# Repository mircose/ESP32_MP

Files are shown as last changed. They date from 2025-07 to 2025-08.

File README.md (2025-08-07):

# ESP32_MP
## CD Quality Digital Audio Player and Streamer

You can watch a video explanation of this project [HERE](https://pages.github.com/)

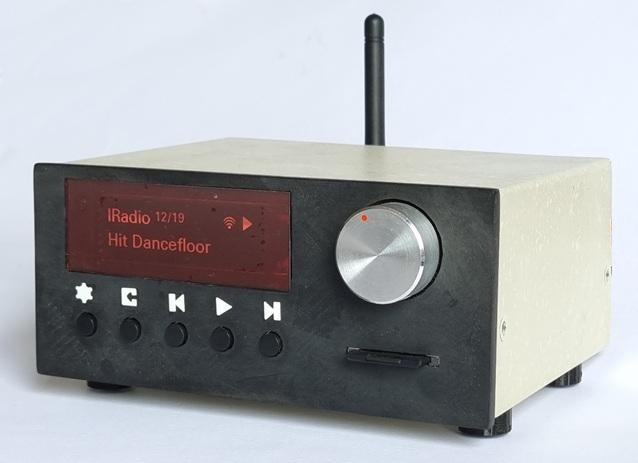
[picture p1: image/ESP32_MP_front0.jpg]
ESP32-MP_front


### This repository contains a complete project of Audio Player that implements:

*  Play from SD Card
*  Streaming from Internet Radio
*  Streaming from UPnP media server
*  Streamin from Bluetooth

### The main features are:

*  OLED Display for real time information
*  Button and knob to full control
*  Operated remotely with a IR remote control
*  Advanced Web Server for radio station manage

Supported audio formats: 	MP3, FLAC, WAV, AAC (up to 48 kHz, 16 bit)  
Maximum bit rate: 	1440 kbit/s (FLAC, WAV) 320 kbit/s (MP3, AAC)

### User Manuals:
See the manuals section for complete information
* User Manual Hardware to understand how to build it
* User Manual Software with operating instructions
* User Manual Firmware to understand how to test the hardware and load the firmware
* RMAA ESP32_MP Measure (pre out) with [RMAA Audio Test Software](https://audio.rightmark.org/products/rmaa.shtml)

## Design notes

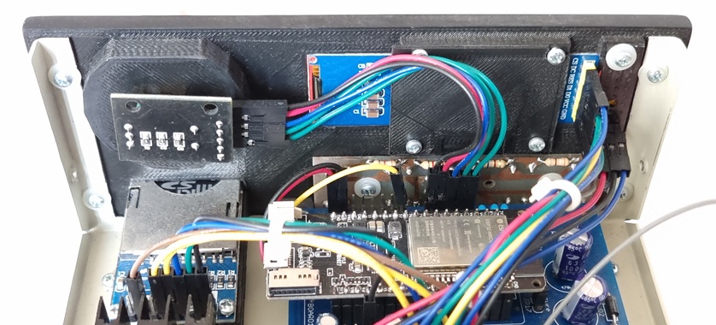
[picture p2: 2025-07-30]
image/ESP32_MP_internal2.jpg

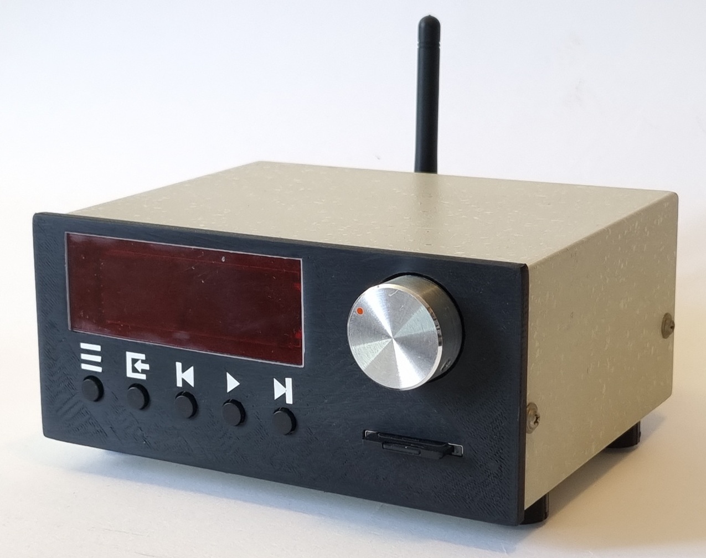
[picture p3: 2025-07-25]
image/ESP32_MP_front2.jpg

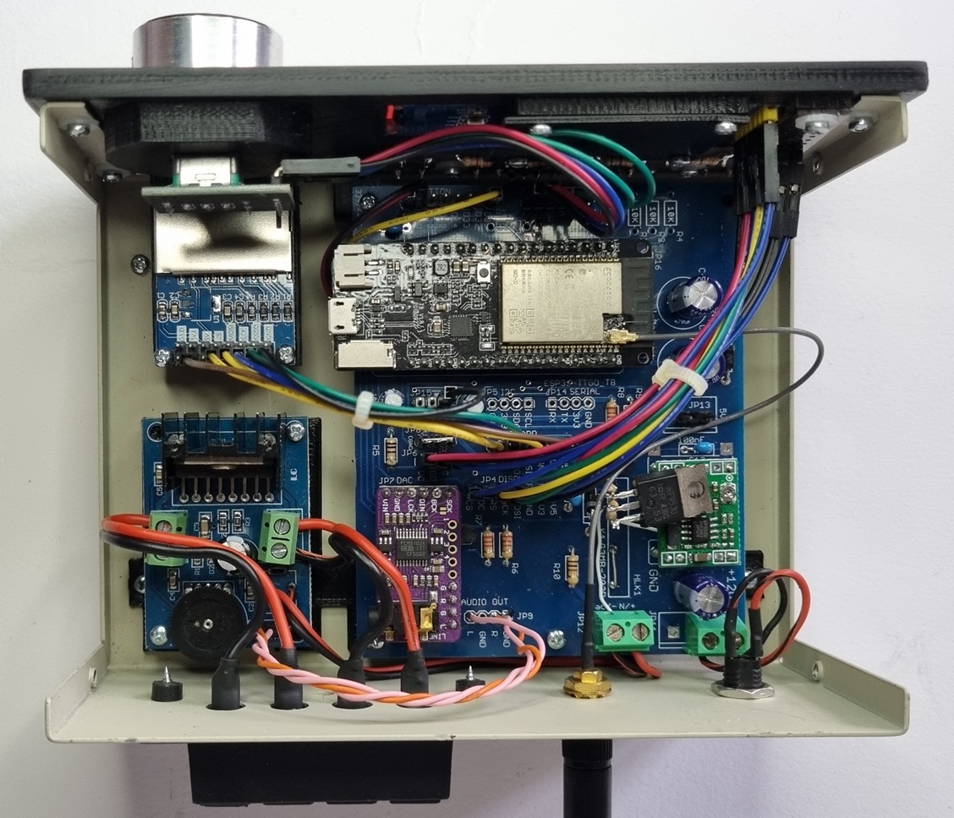
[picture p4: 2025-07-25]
image/ESP32_MP_internal.jpg

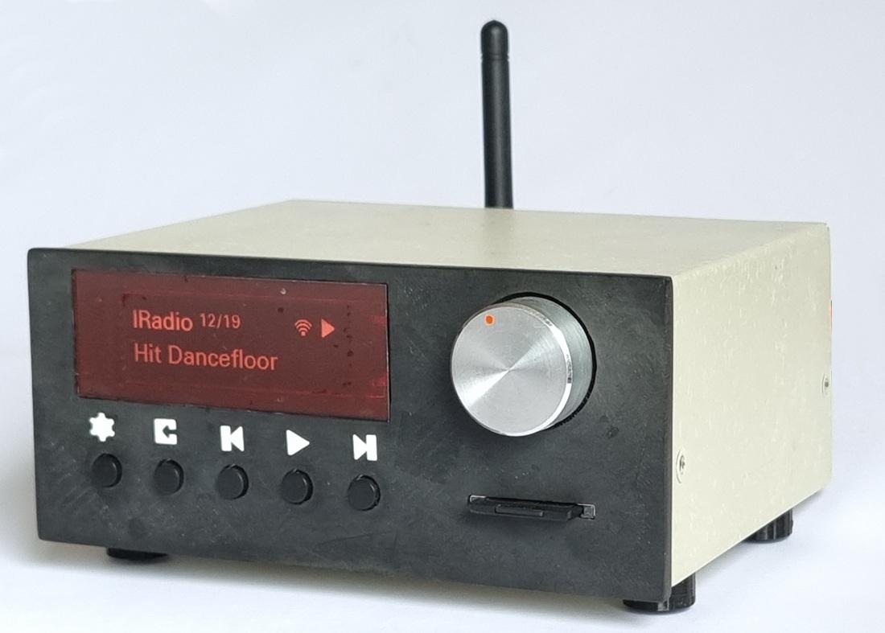
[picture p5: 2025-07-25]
image/ESP32-MP_front.jpg

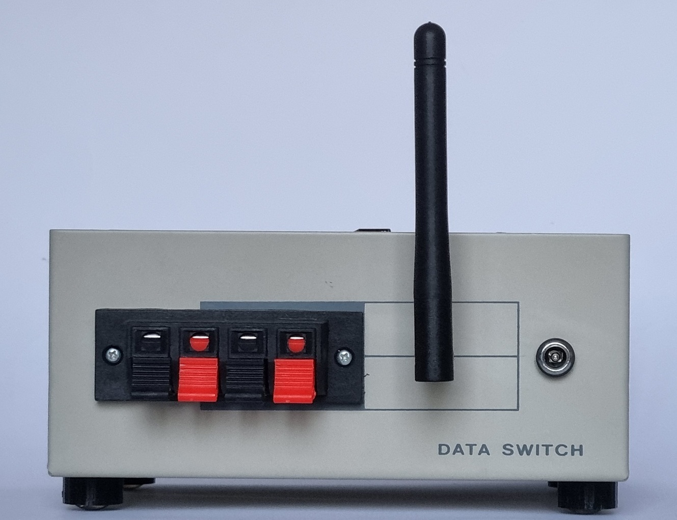
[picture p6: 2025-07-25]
image/ESP32_MP_rear.jpg

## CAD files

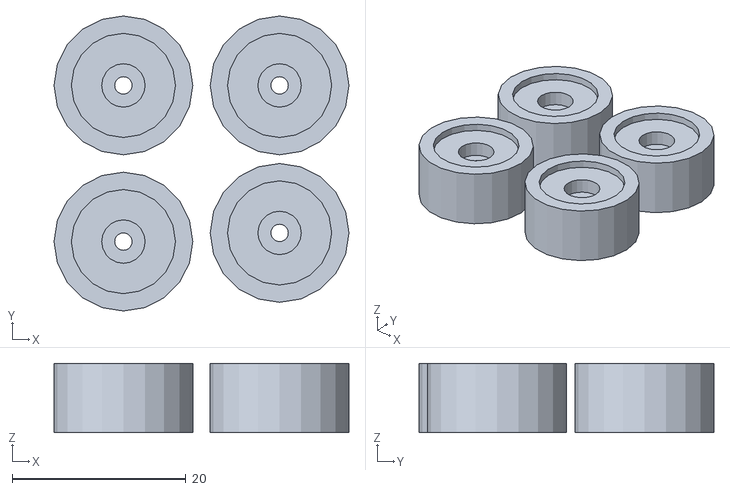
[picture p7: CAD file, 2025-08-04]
3D files/ESP32_MP_feet.stl
34.0 x 34.0 x 8.00

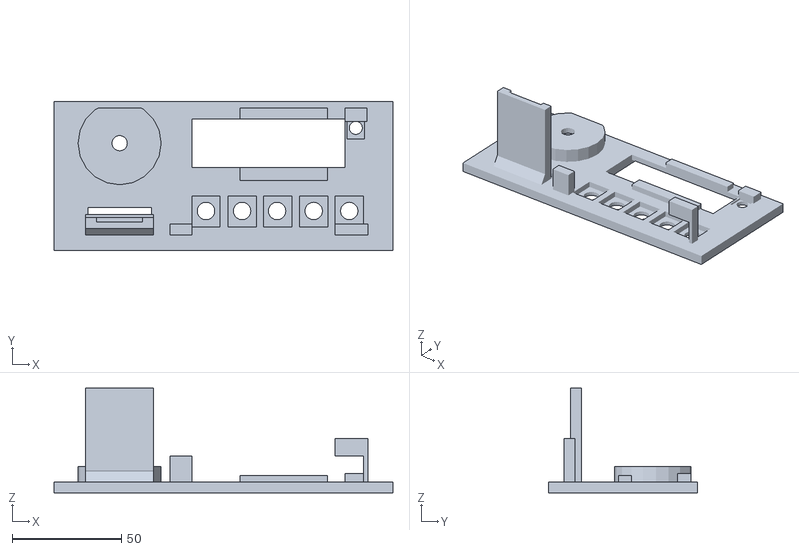
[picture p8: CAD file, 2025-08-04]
3D files/ESP32_MP_front.stl
155.0 x 68.0 x 48.0

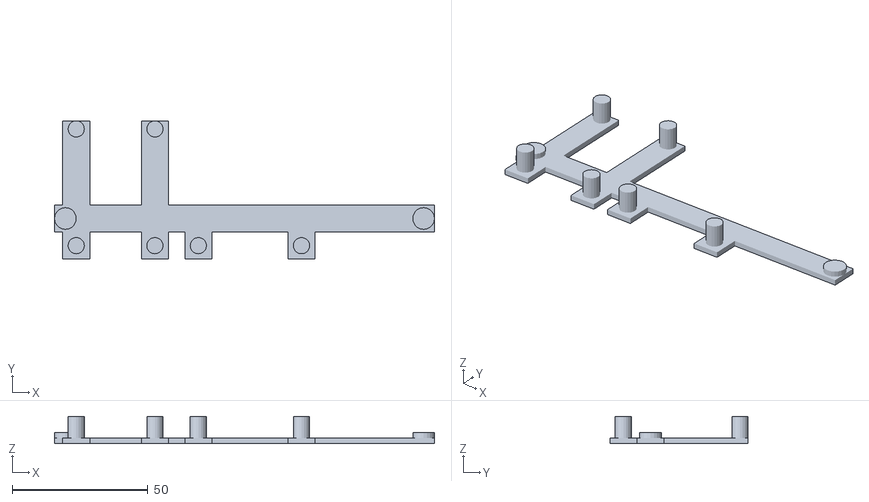
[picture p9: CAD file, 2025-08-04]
3D files/ESP32_MP_support.stl
140.0 x 51.0 x 10.0

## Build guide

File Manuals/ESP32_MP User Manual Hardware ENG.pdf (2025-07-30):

# ESP32_MP

# Digital Music Player and Streamer

## User Manual Hardware

Version ENG july 2025

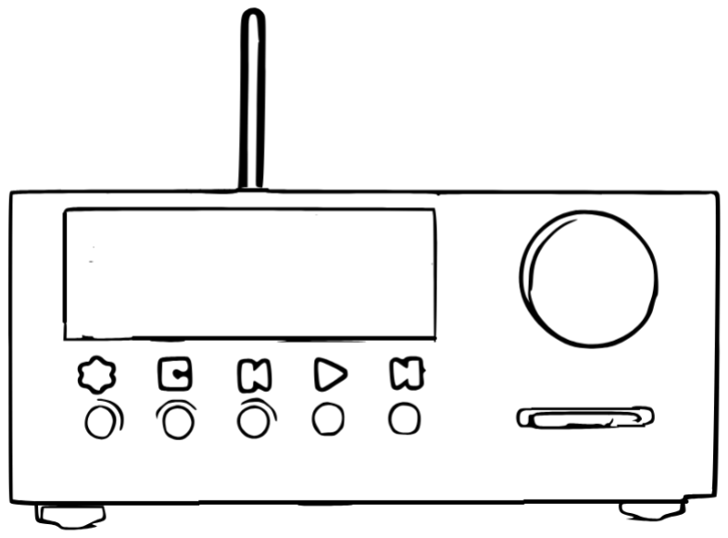
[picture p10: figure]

CD Quality Digital Music Player and Streamer Streaming from Internet Radio
Streaming from UPnP media server
Streamin from Bluetooth
Play from SD Card

# Table of contents

1. Introduction and disclaimer
2. Main board
3. Push button board
4. Componets modify
5. Assembly option#1
6. Assembly option#2
7. Assembly in case

# 1.Introduction and disclaimer

This document describe construction and assembly the ESP32_MP multimedia player. This is a hobbyist, non-commercial project; therefore, no support is provided, nor is it guaranteed to work properly. It is recommended that you attempt this project only if you have some familiarity with electronics. The author assumes no responsibility for any damage or injury resulting from the realization of this project. This proposal is only one possible solution; everyone can make any changes and improvements they deem appropriate.

# 2.Main board

All the project files are available in the GitHub repository. Below is the wiring diagram of the main electronic board. The public version uses the ESP32_MP_PCB_V2_REV2 files; in my project, I used the ESP32_MP_PCB_V2 files.

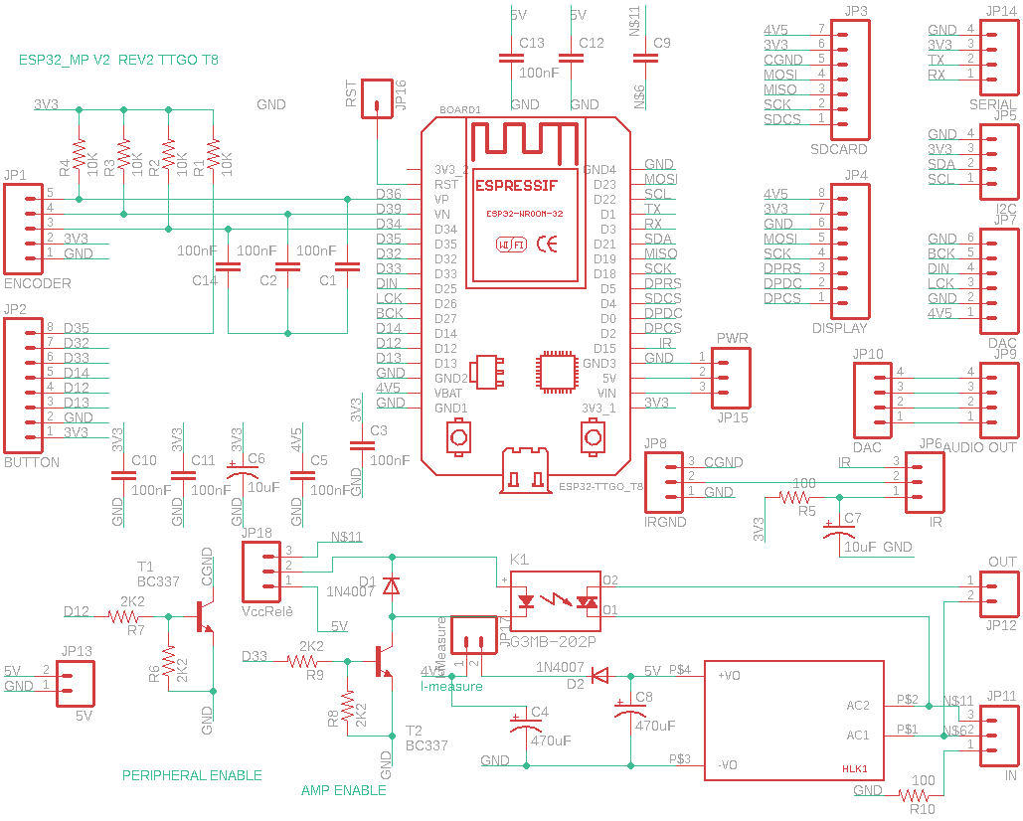
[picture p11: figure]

ESP32_MP Main Board schematic

ESP32_MP Main Board component layout

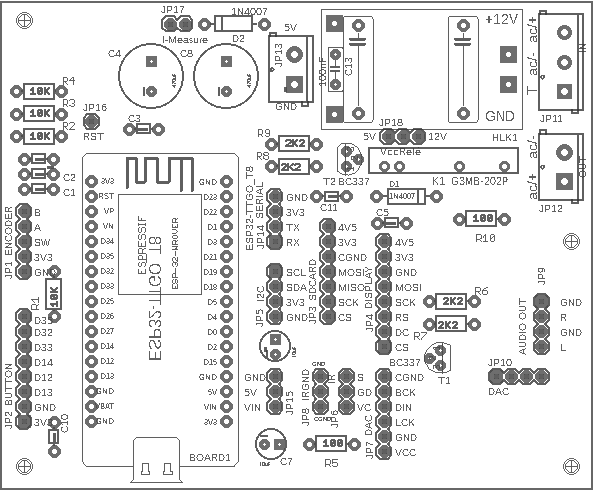
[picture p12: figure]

List of components:
name | Value | note
R1, R2, R3, R4 | Not used | already present on encoder breakout
R5, R10 | Resistor 100 1/4W
R6, R7, R8, R9 | Resistor 2k2 1/4W
D1, D2 | Diode 1N4007
T2 | BJT BC337
T1 | Not used
C1, C2, C3, C5, C9, C10, C11, C12, C13 | Capacitor 100nF 63V
C4, C8 | Capacitor 470uF 25V
C6, C7 | Capacitor 10uF 25V
JP7, JP9, JP10, MCU | Strip Female 2,54mm
JP1, JP2, JP3, JP4, JP6, JP8, JP12, JP15, JP17, JP18 | Strip Male 2,54mm
JP5, JP13, JP14, JP16 | Not used | Expansion connector
JP11, JP12 | Connector screw 5mm
K1 | See next

Additional components and break out board:

name | Value | SKU Futuranet.it

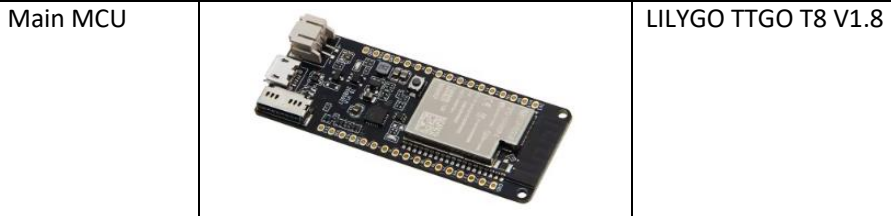
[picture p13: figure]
Main MCU; LILYGO TTGO T8 V1.8

DAC | PCM5102A | 2846-I2SPCM5102A
Encoder W/button | Encoder breakout 12mm YC093 | 8300-YC093
IR Sensor | IR38DM | 8220-IR38DM
Display | OLED SPI 2,08” 256x64 HM25664A208W02 | 2846-SPIOLED208

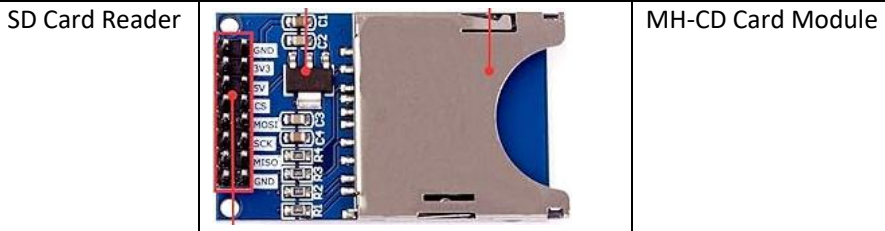
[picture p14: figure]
SD Card Reader; MH-CD Card Module

IR remote control | H96MAX model

# 3.Componets modify

For optimise system consumption and functionality It is recommended (but not necessary) some modify to components.
1. Remove LDO from SD Card Module.

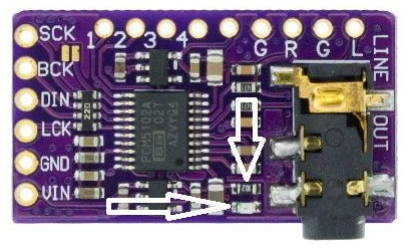
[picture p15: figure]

2. Cut wire of LED or remove LED or Remove resitor from DAC Module.

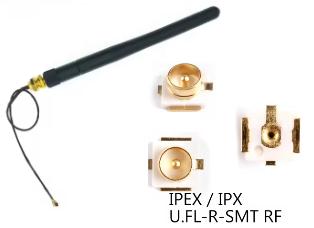
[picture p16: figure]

3. Most ESP32 boards come with an internal antenna. If you use a metal case, this may affect the WiFi signal. In this case, you'll need to add an external antenna to the ESP32 module using the appropriate antenna pads. You need to get an antenna with the corresponding IPX connector compatible with ESP32 board. Very carefully solder the ipx connector on the esp32 board and move the resistor that switches from internal to external antenna.

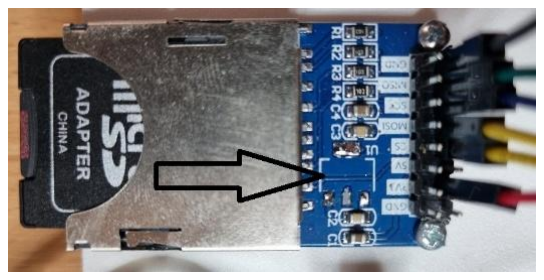
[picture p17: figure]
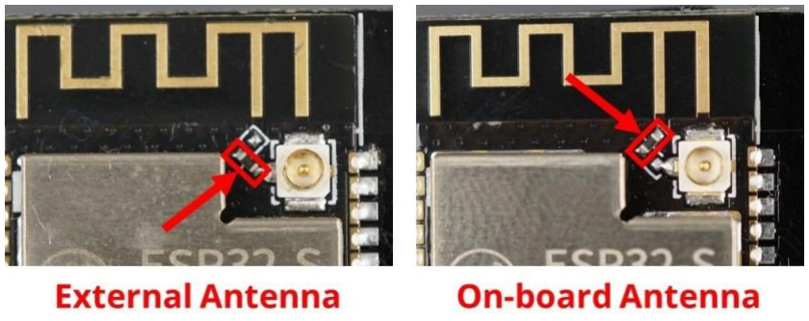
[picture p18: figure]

# 4.Push button board

ESP32_MP Push button board schematics

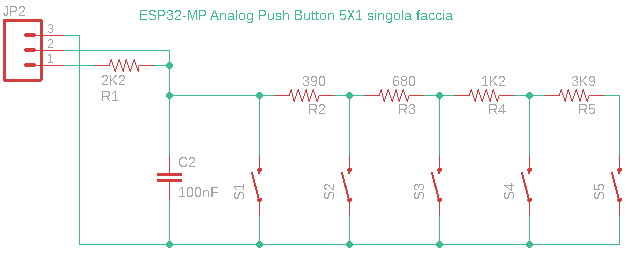
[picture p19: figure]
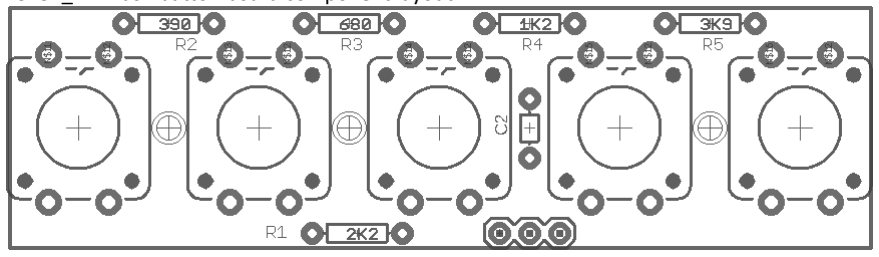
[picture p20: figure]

ESP32_MP Push button board component layout

List of components:
name | Value | note
R1 | Resistor 2k2 1/4W
R2 | Resistor 390 1/4W
R4 | Resistor 1k2 1/4W
R5 | Resistor 3k9 1/4W
C2 | Capacitor 100nF
JP2 | Strip Male 2,54mm
P1, P2, P3, P4, P5 | Push button 12x12mm

# 5.Assembly options #1

There are two possible configurations based on the type of power supply and amplifier. In option #1 use a 12VDC power supply by AC/DC Wall power adapter for powered the player. The amplifier is powered by 12VDC ( the power of amplifier is limited by this voltage).

List of components:
name | Value | SKU Futuranet.it
Power adapter | 230VAC/12V 1A | 8260-PSSE1210
HLK1 DC/DC Converter | 12VDC to 5VDC step down converter | 3085-MP1584ADJ
Power plug | Panel plug 5,5 x 2,1 mm | 1606-DCPLUG

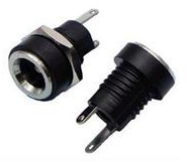
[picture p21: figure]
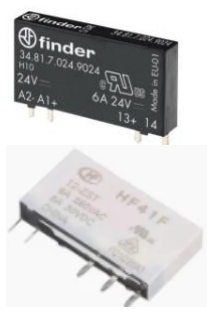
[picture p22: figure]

K1 | Finder 34.51 12V OR Finder 34.81.7.012.9024 OR HF41F 12-ZS OR HF41F 12-HS OR DIY MOSFET RELAY | For power amplifier
Power amplifier | TDA7297 Amplifier board Single power supply 12VDC 8+8W @12V | If you want only preamplifier output this isn’t necessary.

K1 DIY MOSFET RELAY

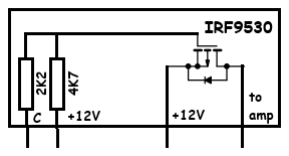
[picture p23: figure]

Alternatively the 230Vac/12VDC power supply can be inserted
inside the case:

Assembly schematics Please Note:

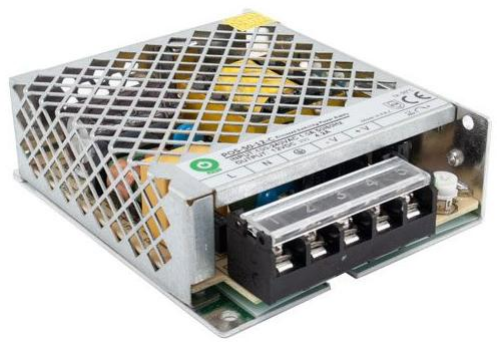
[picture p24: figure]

JP17 it's a useful connector to measure absorbent current. Short circuit the pins in normal operation. JP13 it’s used to measure ESP32 board power voltage.
JP8 it's possible to reduce current consumption in standby mode disable gnd power from SD card, DAC and IR sensor by T1. But not great advantage, in normal use short circuit the three pins.
JP6 for max stability connect 100nF capacitor as to close beetwin pin Vcc e GND of IR38DM IR sensor. JP5, JP14 and JP15 are connectors for future expansion functions.
JP18 connect the central pin to 12V, this is a voltage to control relay.
Connect the power adapter 230Vac/12VDC at main power plug.

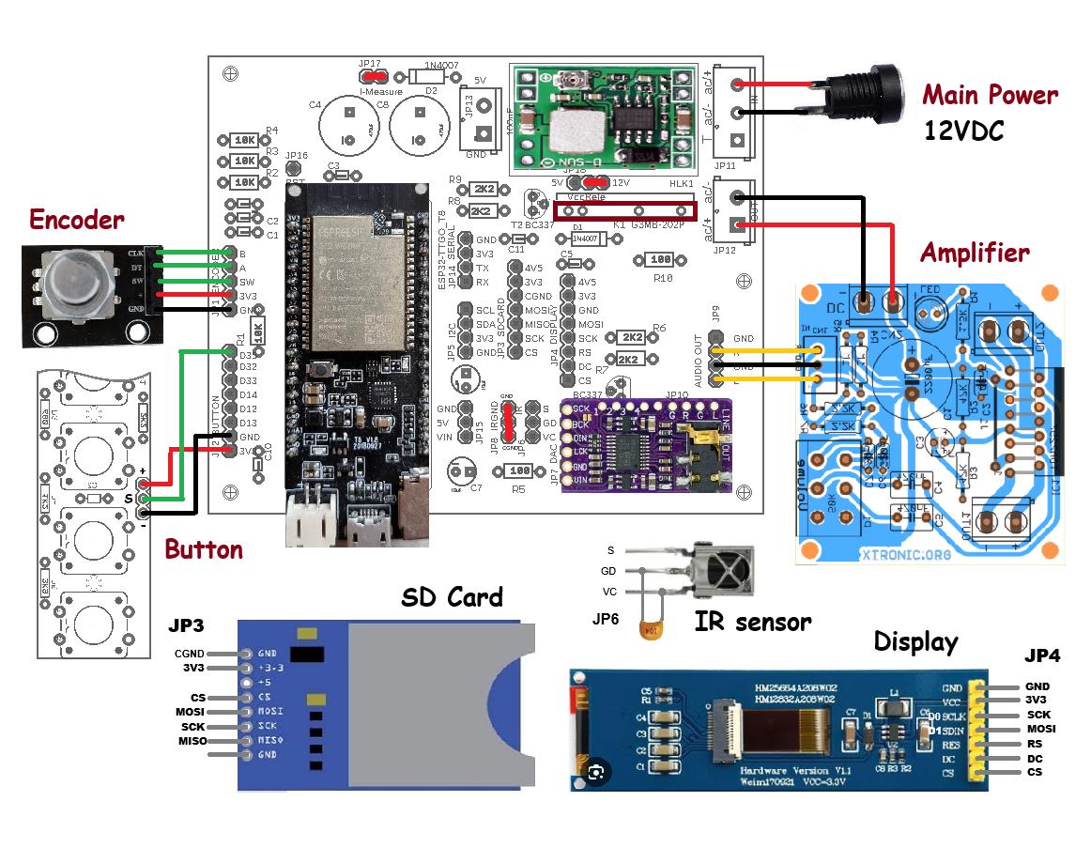
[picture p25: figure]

# 6.Assembly option #2

In option #2 use a 230Vac power supply and secondari AC/DC converter for powering amplifier. There is not limitation amplifier power.

List of components:
name | | Value | SKU Futuranet.it

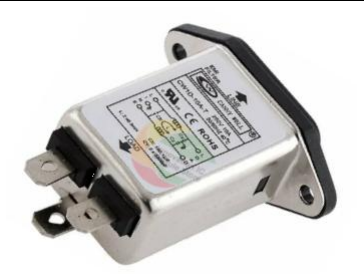
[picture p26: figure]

Power plug | OR | VDE panel plug 250 VAC | 8300-POWERSOCKET2

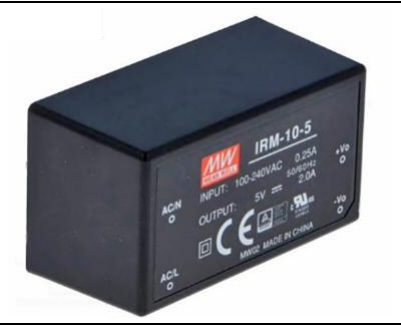
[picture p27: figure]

HLK1 AC/DC adapter | | 230Vac to 5VDC adapter | 8420-IRM-10-5
K1 | | State solid Realy Omron G3MB-202P Input 5VDC Output 240Vac 2A | 8300-YL051

For power amplifier (Example): Transformer 230Vac/24+24Vac Converter 2xAC/2xDC
Power amplifier
There are some options…

Assembly schematics Please Note:
JP17 it's a useful connector to measure absorbent current. Short circuit the pins in normal operation. JP13 it’s used to measure ESP32 board power voltage.
JP8 it's possible to reduce current consumption in standby mode disable gnd power from SD card, DAC and IR sensor by T1. But not great advantage, in normal use short circuit the three pins.
JP6 for max stability connect 100nF capacitor as to close beetwin pin Vcc e GND of IR38DM IR sensor. JP5, JP14 and JP15 are connectors for future expansion functions.
JP18 connect the central pin to 5V, this is a voltage to control relay.
Connect the power supply 230Vac at main power plug

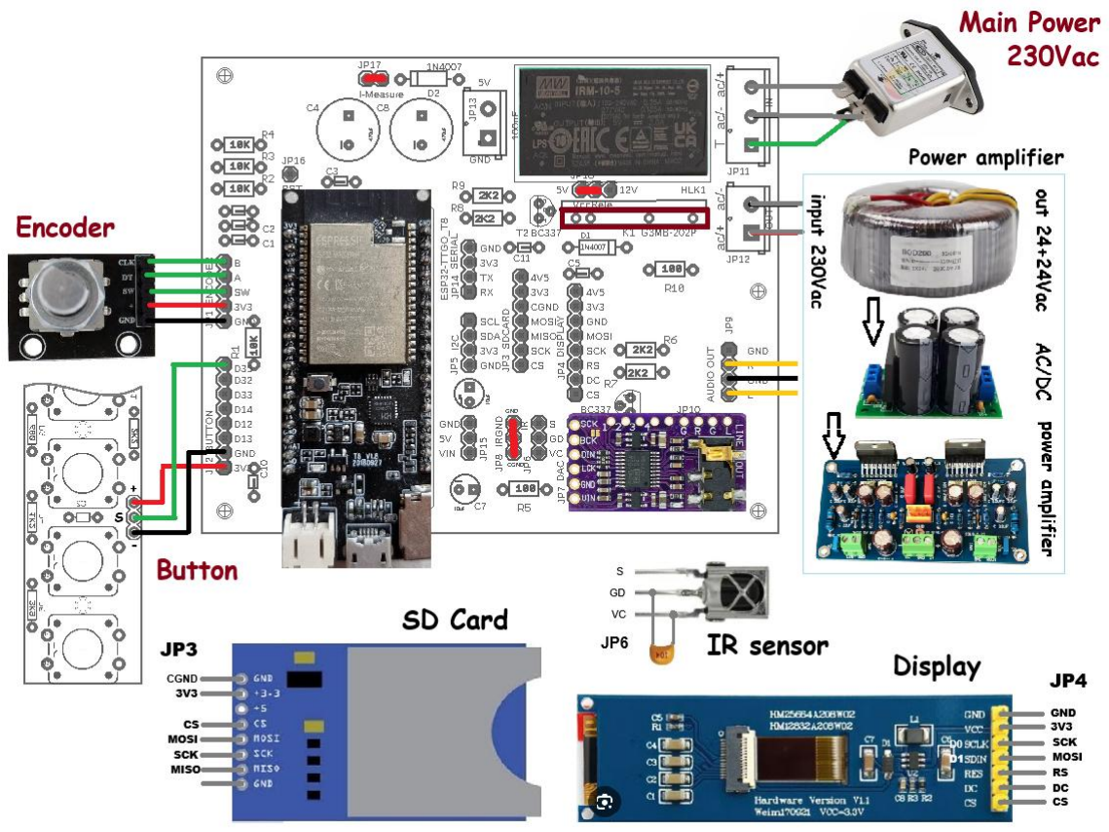
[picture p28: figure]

Additional options for the power amplifier:

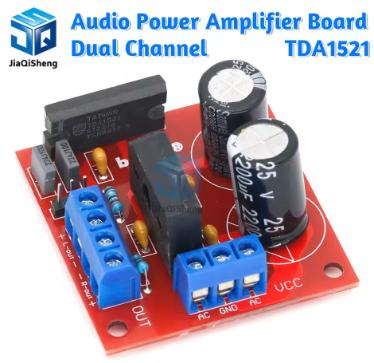
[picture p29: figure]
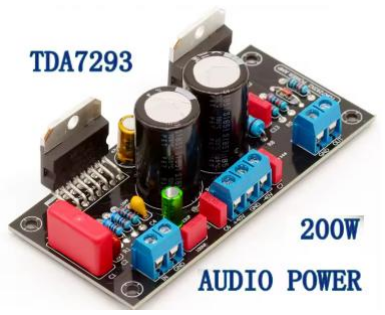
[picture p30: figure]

# 7.Assembly in case

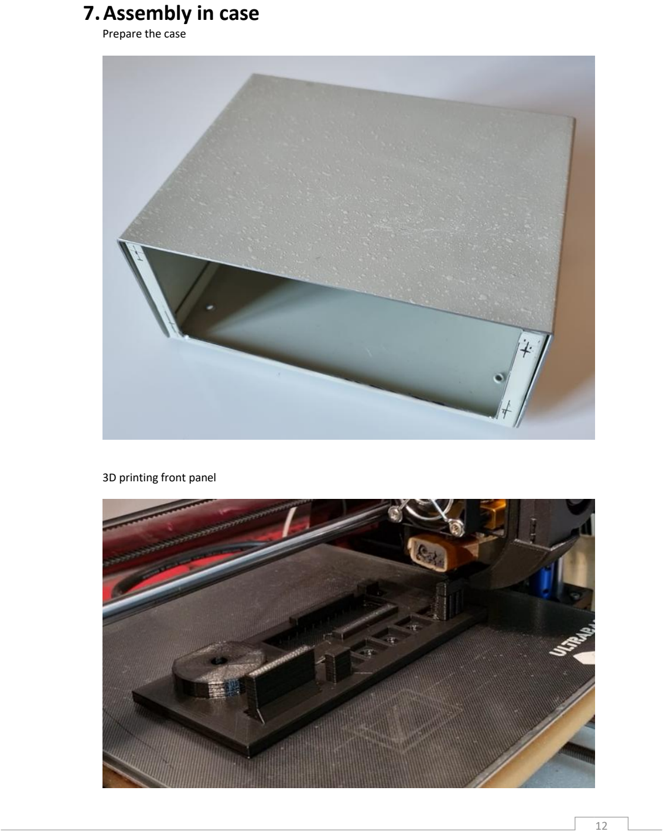
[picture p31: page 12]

Prepare the case

3D printing front panel

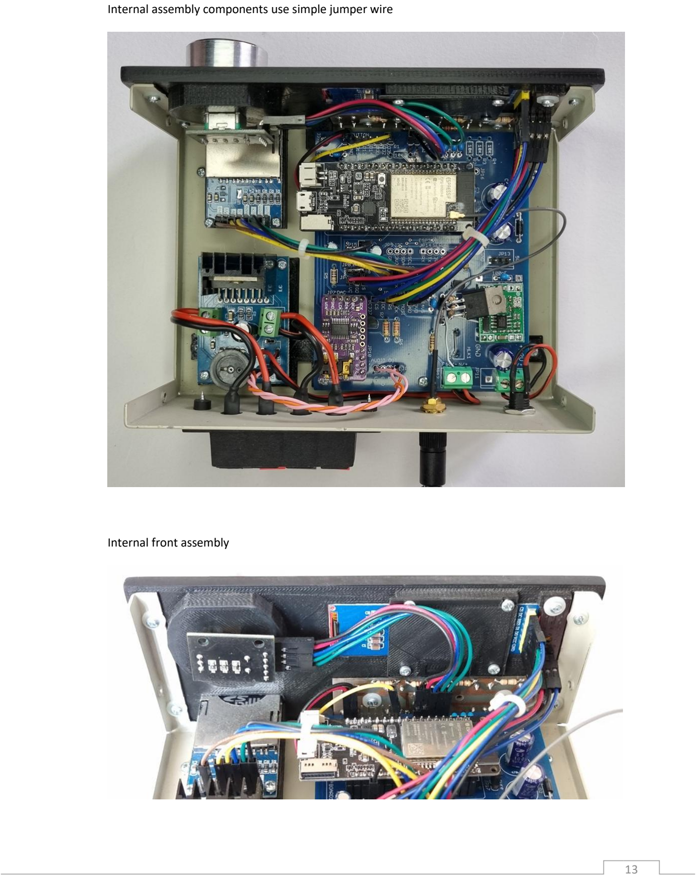
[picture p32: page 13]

Internal assembly components use simple jumper wire

Internal front assembly

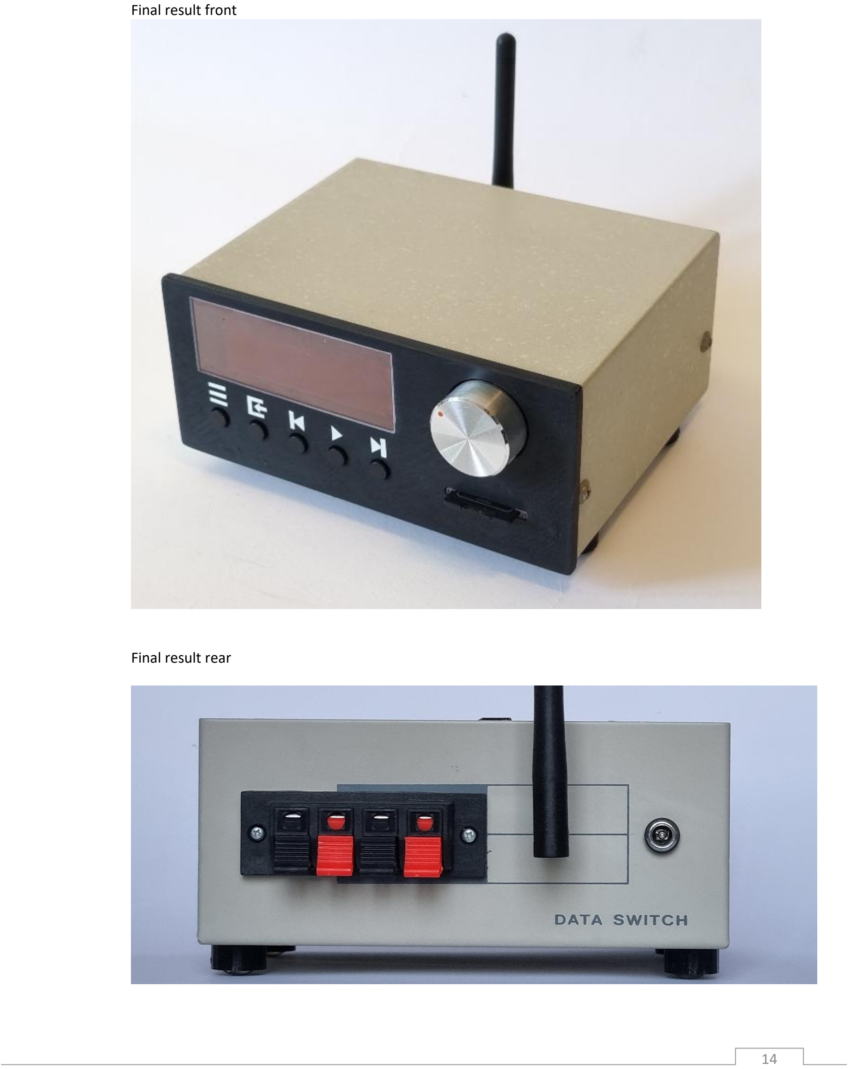
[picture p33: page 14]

Final result front

Final result rear

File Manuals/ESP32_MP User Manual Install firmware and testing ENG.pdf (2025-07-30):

# ESP32_MP

# Digital Music Player and Streamer

## Install Firmware and testing

Version ENG july 2025
firmware version 20250724


CD Quality Digital Music Player and Streamer Streaming from Internet Radio
Streaming from UPnP media server
Streamin from Bluetooth
Play from SD Card

# Content

1. Testing
2. Install firmware
3. First start

# 1.Testing

Once the hardware has been completed by assembling all the components as described in the relevant manual, it’s possible to install the firmware that enables all the player's features. in this case you can skip the following chapters and read the chapter relating to the firmware installation. If you want it’s possible testing each individual component. To perform the tests described below you need to have the necessary skills in using the Arduino IDE. Testing requires the Arduino IDE on PC, connected via serial to the ESP32 MCU board.

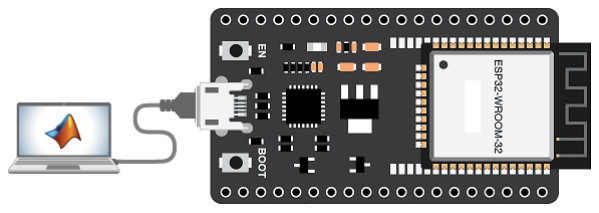
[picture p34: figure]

The online repository at https://github.com/mircose/ESP32_MP provides all the documentation needed to build and test the player. Among the files are some sketches that can be used to test a specific hardware component of the project. These sketches must be opened in the Arduino IDE and uploaded to the ESP32 module via the serial connection. for some sketches it will be necessary to install the appropriate library. All these sketches use the Arduino Serial Monitor to provide a performance report. The expected reports are available in each sketch's folder.

# 2.Install Firmware

Given the complexity of the project and the difficulty of managing many libraries, some of which have been modified, the precompiled .bin file is provided, which is much easier to install. Download the latest firmware version in .bin format from the repository.
Dowload Espressif Flash Download Tools from https://www.espressif.com/en/support/download/other-tools

Connect the player to the PC with the serial cable and run Flash Download tools. Set ESP32 Chip Type
WorkMode Develop
LoadMode UART

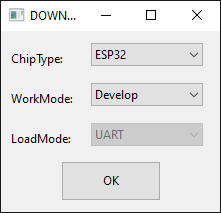
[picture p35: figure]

Open ESP32_MP_xxxxxxxx.bin compiled firmware and set with image below. Make sure to check the file selection and enter the value 0x0 as the address, then click START.

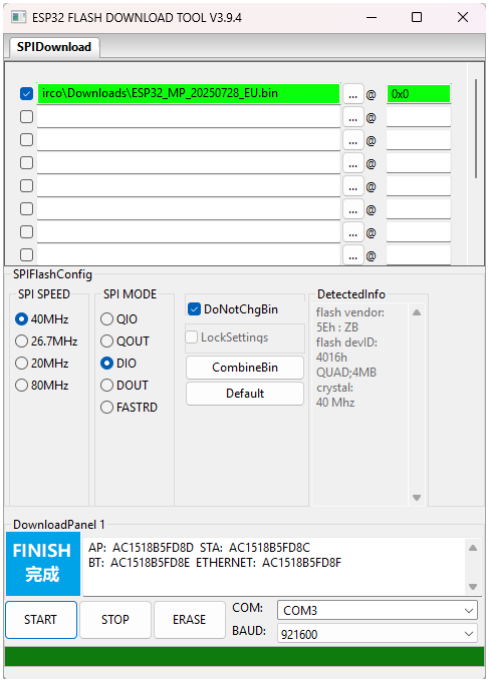
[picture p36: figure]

wait for the operation to complete.

# 3. First start

After completing the firmware upload, unplug the serial cable. If the player was powered, press the reset button on the ESP32 board to start running the program. If the player was not powered, power it on.
At first start-up, the default settings are present and the first prompt on the screen tells you to select the listening source.

If you select SD Player or Bluetooth Streamer don’t need to configure WiFi network.

If you select Internet Radio or UPnP you need to configure WiFi network.

For details on how to set up your WiFi network and player features please see the file ESP32_MP User Manual Software ENG.pdf

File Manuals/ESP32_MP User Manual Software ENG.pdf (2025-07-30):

# ESP32_MP

# Digital Music Player and Streamer

## User Manual Software

Version ENG july 2025
Firmware version 20250726


CD Quality Digital Music Player and Streamer Streaming from Internet Radio
Streaming from UPnP media server
Streamin from Bluetooth
Play from SD Card

# Content

1. Components and functions
2. Menu configuration
3. WiFi configuration
4. internet Radio
5. Radio Station configuration
6. UPnP Player
7. SD Player
8. Bluetooth
9. Remote control
10. Display
11. Characteristics

# 1.Components and function

The media player features a display for information, a series of buttons, and a multifunction knob that also functions as a button. Description of the features available on the front of the player.

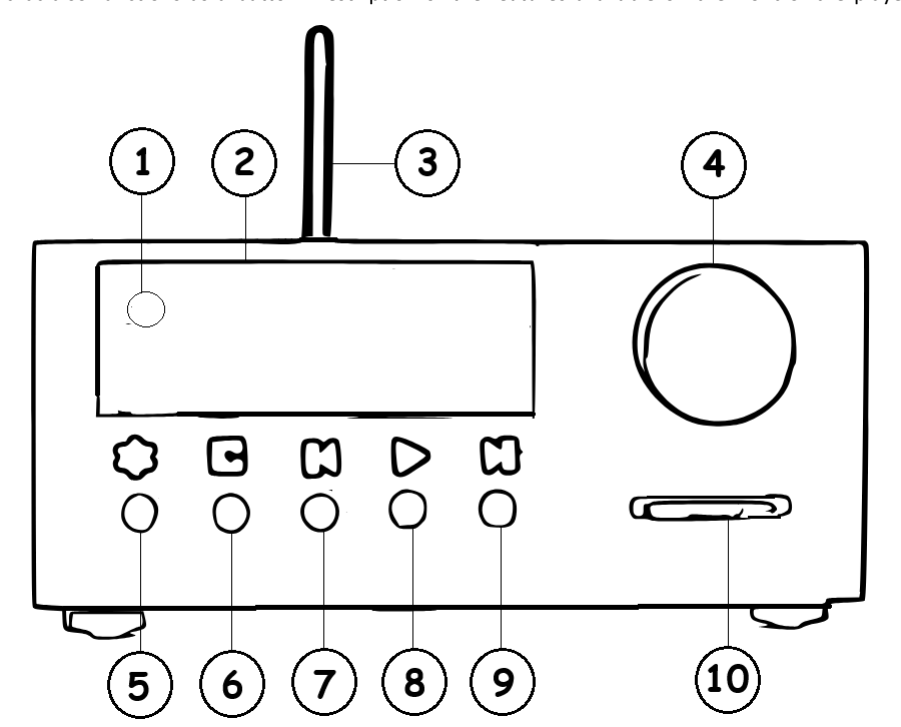
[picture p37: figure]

1 IR sensor
2 Display
3 Antenna
4 Knob set volume / select track (press to confirm) / On-Off 5 Settings
6 Input Select
7 Track forwards
8 Play / Pause
9 Track backwards
10 SD Card slot

To turn the device on, briefly press the knob; to turn it off, press and hold the knob. During standby mode, the unit can be programmed to display the date and time on the display. In standby mode, power consumption is higher, and Wi-Fi and internet access are required for automatic clock synchronization. If you choose not to display the clock in standby, power consumption will be lower, and internet access will only be required when listening to internet radio.

Description of the features available on the back of the player.

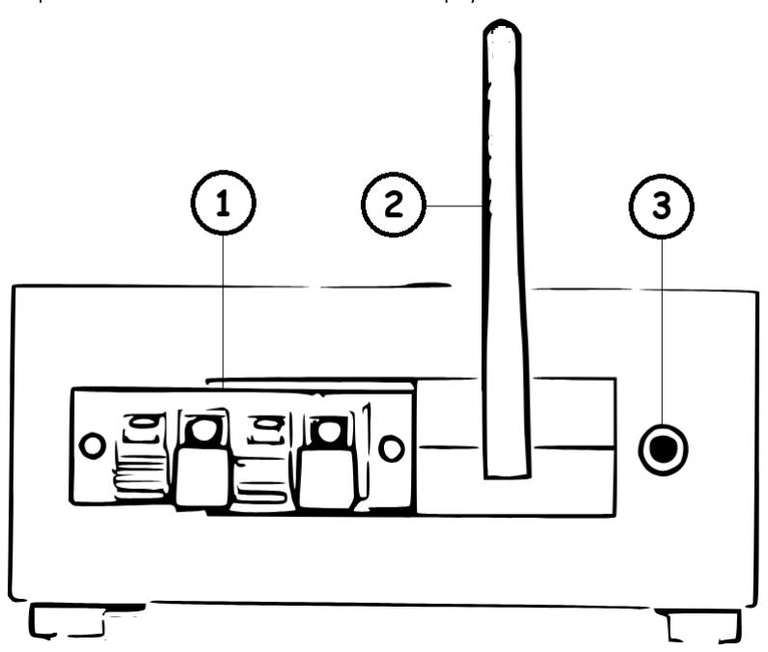
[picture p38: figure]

1 Speaker connector
2 Antenna
3 Power connector

Connect the speakers to the left and right speaker jacks (speaker output) on the back of the unit. To do this, press the spring clips and insert the loose wire ends into the designated openings.
Connect the external antenna for WiFi access. Connect the external power supply or power plug, depending on the hardware version you have assembled.

# 2.Menu configuration

Read Favor. radio
Your favorite radio stations are saved in the ESP32's internal memory, and they can be read and added to the playlist. The next command (Read radio in SD) lets you load the list of stations saved in SD into the playlist. If this was your last setting, you will find it every time you start the player.

Read radio in SD
Select the radio playlist on the SD card. In the SD card, you can create a folder called RadioPlaylist containing Text files. Each file contain the list of stations divided by genre or content. For example you can create (internal RadioPlaylist folder) a file called Country.txt that contains only country radio stations. The lines in this file is in format: “station name” followed by comma followed by “URL” example:

Radio Country,https://stream.laut.fm/country

Country NY,http://ns2.kmeathosting.com:8000/wtrb Music Country,http://s1.logical.systems:9000/
Country Music FM,https://stream.laut.fm/countrymusicfm

Read audio in SD
Loads the songs present in SD (mp3, FLAC...) into the play list (this is done automatically every time you select SD Player).

Scan UPnP Server
It scans the network for all media players and then allows you to select the one that will be the default each time you start the device.

No repeat
The selected song will repeat only once.

Repeat single
The selected song repeats continuously.

Repeat all
Plays all songs in sequence.

Repeat random
Play all songs in shuffle mode.

NB Repeat modes are only valid in SD Player and UPnP Player mode.

Configure WiFi
Set up your WiFi access credentials.

Disable Amp
Disable amplifier power.

Enable Amp
Enable amplifier power.

StandBy deep
Standby in deep sleep mode. Power ON only via knob button.

StandBy clock off
Standby without clock on display. Power ON via knob button and remote control.

StandBy clock on
Standby with clock on display. Power ON via knob button and remote control. Valid only for Central European country.

Info
Displays the firmware version and network name.
The firmware version corresponds to the date it was uploaded.

NB Some functions are only active when you are in the relevant mode. NB For Standby detail view technical specifications manual

# 3.WiFi configuration

The device can operate in SD Player and Bluetooth streamer modes without requiring WiFi access. To use the UPnP Player functionality, you must connect to a WiFi network with a discoverable UPnP server. For Internet Radio functionality, you must be connected to a WiFi network with Internet access.
Use the buttons on the main unit to access the menu, rotate the dial to Configure WiFi, and then confirm by pressing the dial.

The ESP32 module will configure a local network (access point) to which you should connect with a mobile device. Open settings in you mobile devoce and connected to the network named ESP32_MP, launch your browser and enter the URL 192.168.4.1. The Web Server for connection management will open. Click Configure WiFi and follow the instructions on the display.
Once the configuration is complete, the device will automatically reboot.

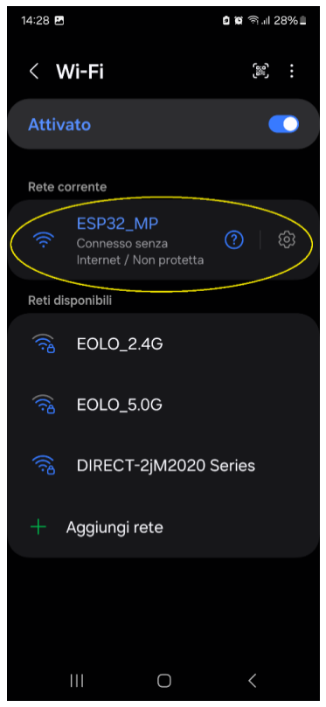
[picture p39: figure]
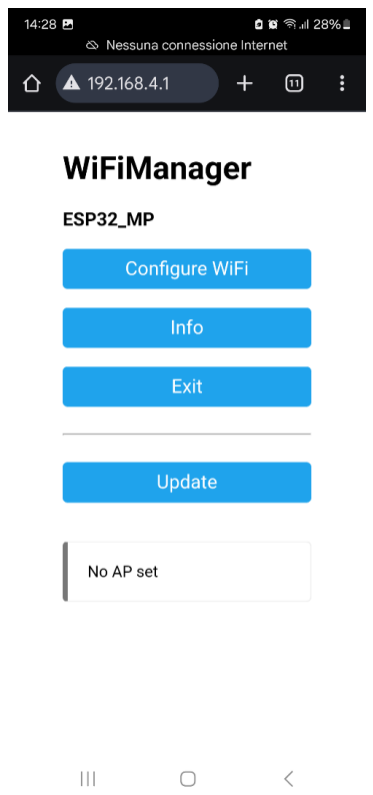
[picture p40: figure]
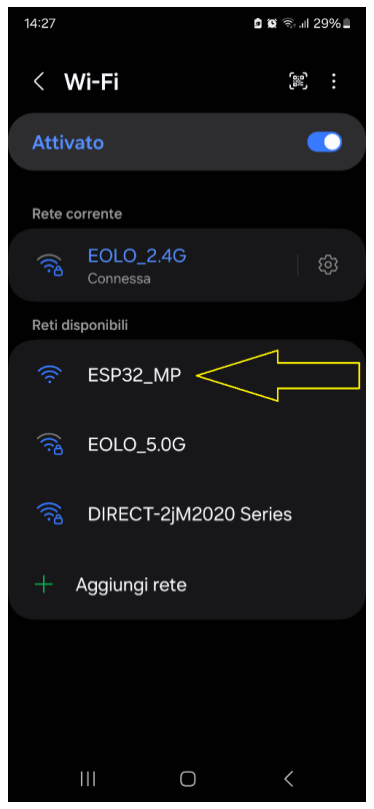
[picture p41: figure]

# 4.Internet Radio

Press the source selection button on the main unit or remote control until iRadio appears on the display. The software will automatically load the default songs saved in the internal memory into the playlist. Playback will automatically start from the last selected station. Use the Next and Previous buttons to select the next or previous song. By clicking the knob or OK on the remote control, you can open and scroll through the song list for easier selection..

# 5.Radio station configuration

In Internet Radio mode, open a browser and type http://ESP32_MP. This will open the Web Server for managing radio stations saved in the device's internal memory. From this screen, you can read the list of stored radio stations and control playback. You can use the drop-down menu to select a station and press play to play it. The list contains a maximum of 20 stations. To add a new station, you must first delete a station from the list with the Delete Station button. To add a new station, click Search Station. This will open the Radiolise service, which allows you to search for and listen to radio stations in search of your favorite. After selecting the station you are interested in, click on the menu (three dots) to open the station information. Copy the Name value into the Station Name field of the Web Server and copy the Stream URL value into the Station URL field. Then click Add Station to add the new radio station to the list..

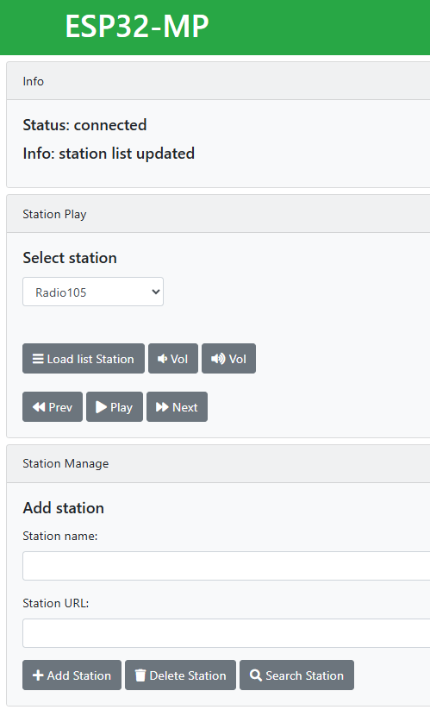
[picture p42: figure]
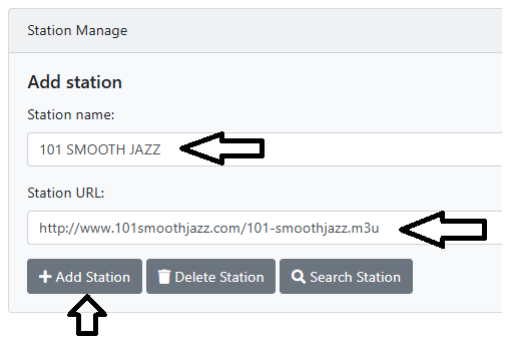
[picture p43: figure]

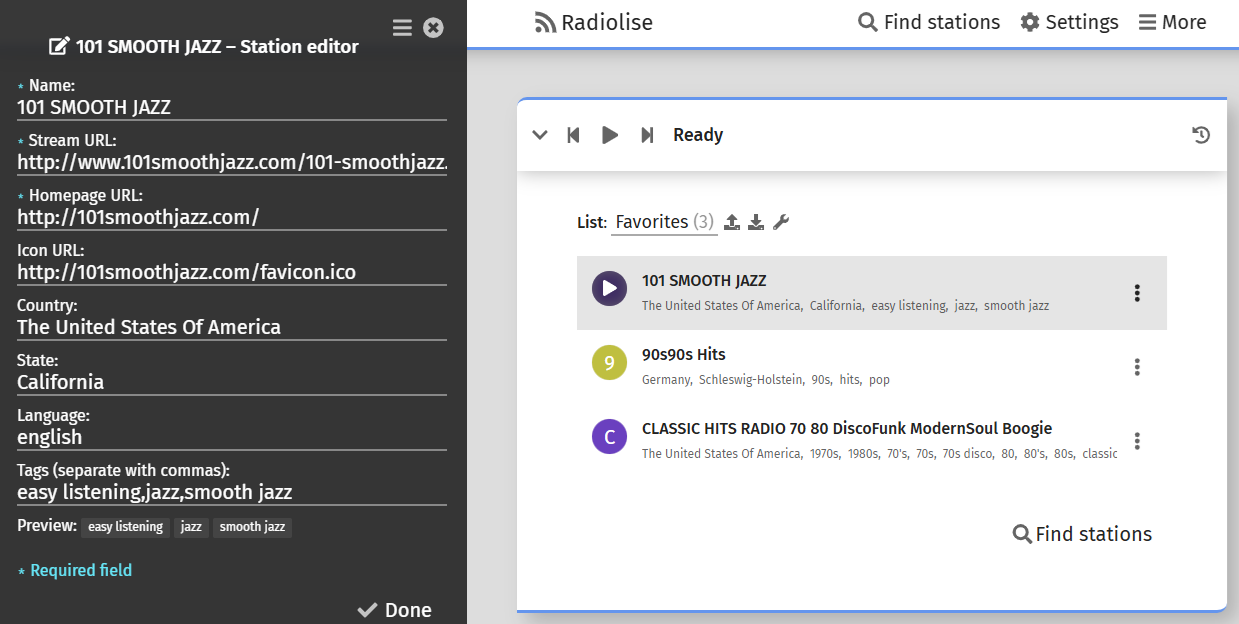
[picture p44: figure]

# 6.UPnP Player

If you haven't already done so, you'll need to scan your WiFi network for UPnP servers. Select Scan UPnP Server from the menu and wait for the operation to complete. If music servers are available, rotate the knob to select the one you want, then confirm by clicking the knob. The server will be saved and used by default each time you start up.
Press the source selection button on the main unit or remote control until UPnP appears on the display. The software will automatically load the songs available on the UPnP server into the playlist. Playback will automatically begin from the last selected station. Use the Next and Previous buttons to select the next or previous song. By clicking the knob and OK on the remote control, you can open and scroll through the song list for quicker selection..

# 7. SD Player

Press the source selection button on the main unit or remote control until SD Player appears on the display. The software will automatically load the list of songs on the SD card into the playlist. Use the Next and Previous buttons to select the next or previous song. By clicking the knob and OK on the remote control, you can open and scroll through the song list for quicker selection.

# 8.Bluetooth

Press the source selection button on the main unit or remote control until Bluetooth appears on the display. The device will wait for a connection from a mobile device such as a smartphone.

On your mobile device, in the settings, select connections and then Bluetooth. In the list of devices listed, click on ESP32_MP to connect. In the music application you're using or in the system settings, you can now use the ESP32_MP player as a media output. The display will show the artist of the song and, if applicable, the song title. From the device, you can control both the song and the playback volume.

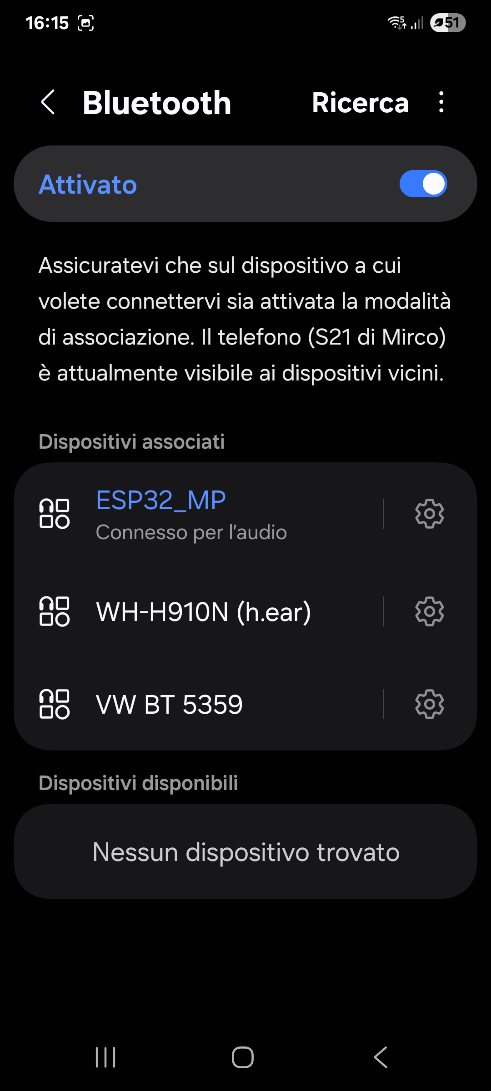
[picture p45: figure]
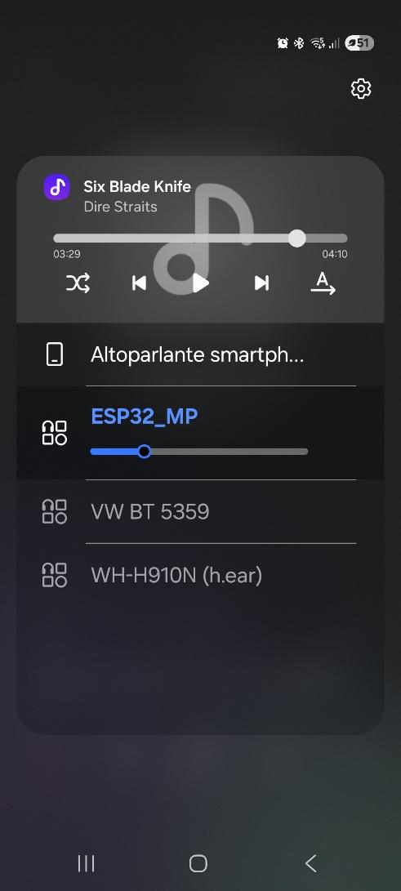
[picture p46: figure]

# 9.Remote control

All functions (except menu management) can be controlled via remote control. The functions are described in the following figure..

Remote control function

1 ON/OFF
2 Display view mode
3 –
4 –
5 Track backwards / Backwars select 6 Track forwards / Forwards select 7 –
8 Select source
9 Decrement volume
10 Increment volume
11 Play / Pause
12 Open select track / Confirm

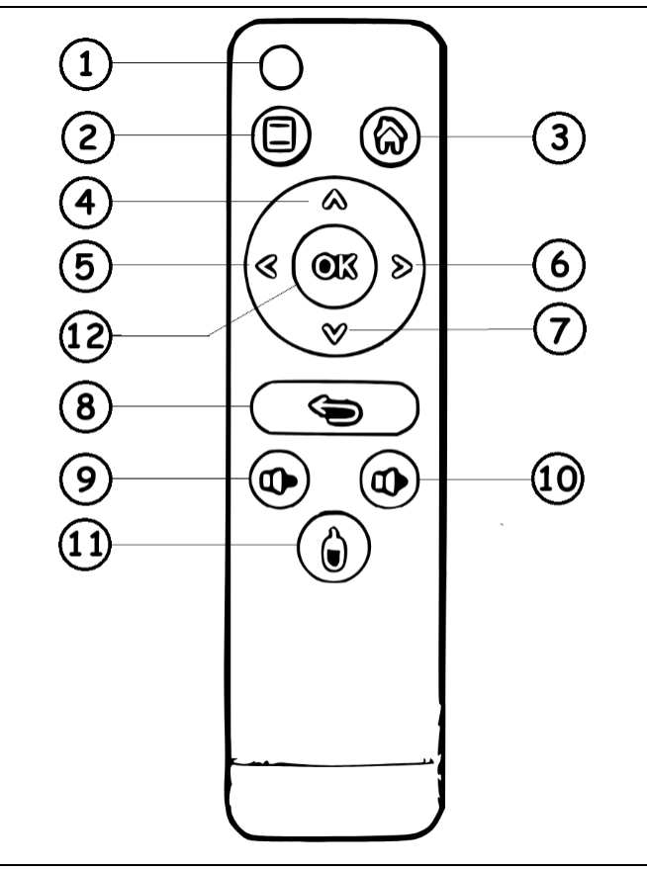
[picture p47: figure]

Repeatedly pressing the display mode button changes the information displayed, as described in the next chapter.

# 10. Display

The display provides real-time information about the operating and playback modes. Repeatedly pressing the Display Mode button on the display changes the information displayed:

Display of operating mode and artist / radio station name

Display artist / radio station name and song title

Display operating mode and playing time

Display simbols
Now Playing

Pause playback

Bluetooth started

No repetition

Repeat the current song

Shuffle Playback

Play in sequence

WebServer started and client connected

WiFi connection OK

Unstable WiFi connection

No WiFi connection

enabled selection

# 11. Characteristics

Technical characteristics ESP32_MP
Power supply
Main power | AC voltage 100 – 240 V
AC input frequency | CA 50/60 Hz
Power consuption | 10 - 80 Watt depends on the configuration
Power consuption in standby (NO clock) | 0,5 Watts
Power consuption in standby (with clock) | 1 Watts
Microprocessor
Series | ESP32-WROVER
CPU | Xtensa dual-core 32-bit LX6
clock | 240MHz
Network connection (WLAN)
Supported networks | WiFi IEEE 802.11a/b/g/n
Supported frequency range | WiFi 2.412 - 2.472 GHz
Player
Supported formats | MP3, FLAC, WAV, AAC (up to 48 kHz, 16 bit)
Maximum bit rate | 1440 kbit/s (FLAC, WAV) From 32 kBit/s to 320 kBit/S (MP3, AAC)
Tags supported | yes
Maximum number of radio stations | 20
Maximum number of songs in SD and UPnP | 250
BLUETOOTH
BLUETOOTH version | V4.2
Power class | Classe 1
Reach | About 10 meters (depending of the environment)

BLUETOOTH profile | A2DP (Advaced Audio Distribution Profile, AVRCP (Audio/Video Remote Control Profile)

Amplifier
| Output power from 2 x 15 Watt to 2 x 30 Watt (depending of the hardware version)

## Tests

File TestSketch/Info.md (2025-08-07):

## ESP32_MP Test Sketch

These are uncompiled Arduino IDe-compatible sketches that can be used to test individual hardware parts of the project before assembling everything.

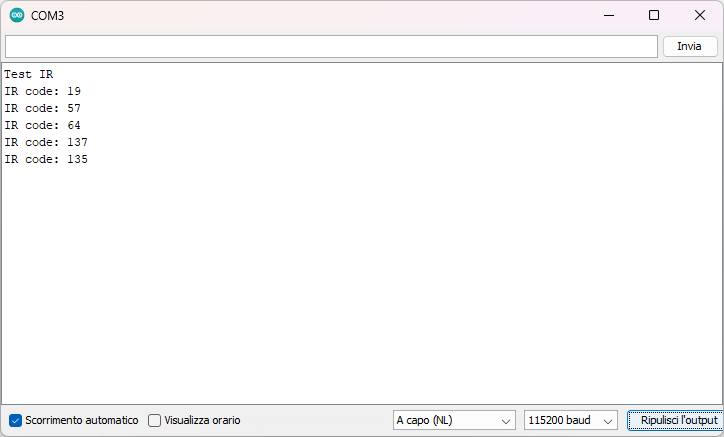
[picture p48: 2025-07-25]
TestSketch/TestIR/TestIR_SerialMonitor.png

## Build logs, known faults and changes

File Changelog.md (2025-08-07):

# Changelog

All notable changes to this project will be documented in this file starting july 2025.

## Version ESP32_MP_20250728_EU.bin

* CHANGELOG created.
* First public version

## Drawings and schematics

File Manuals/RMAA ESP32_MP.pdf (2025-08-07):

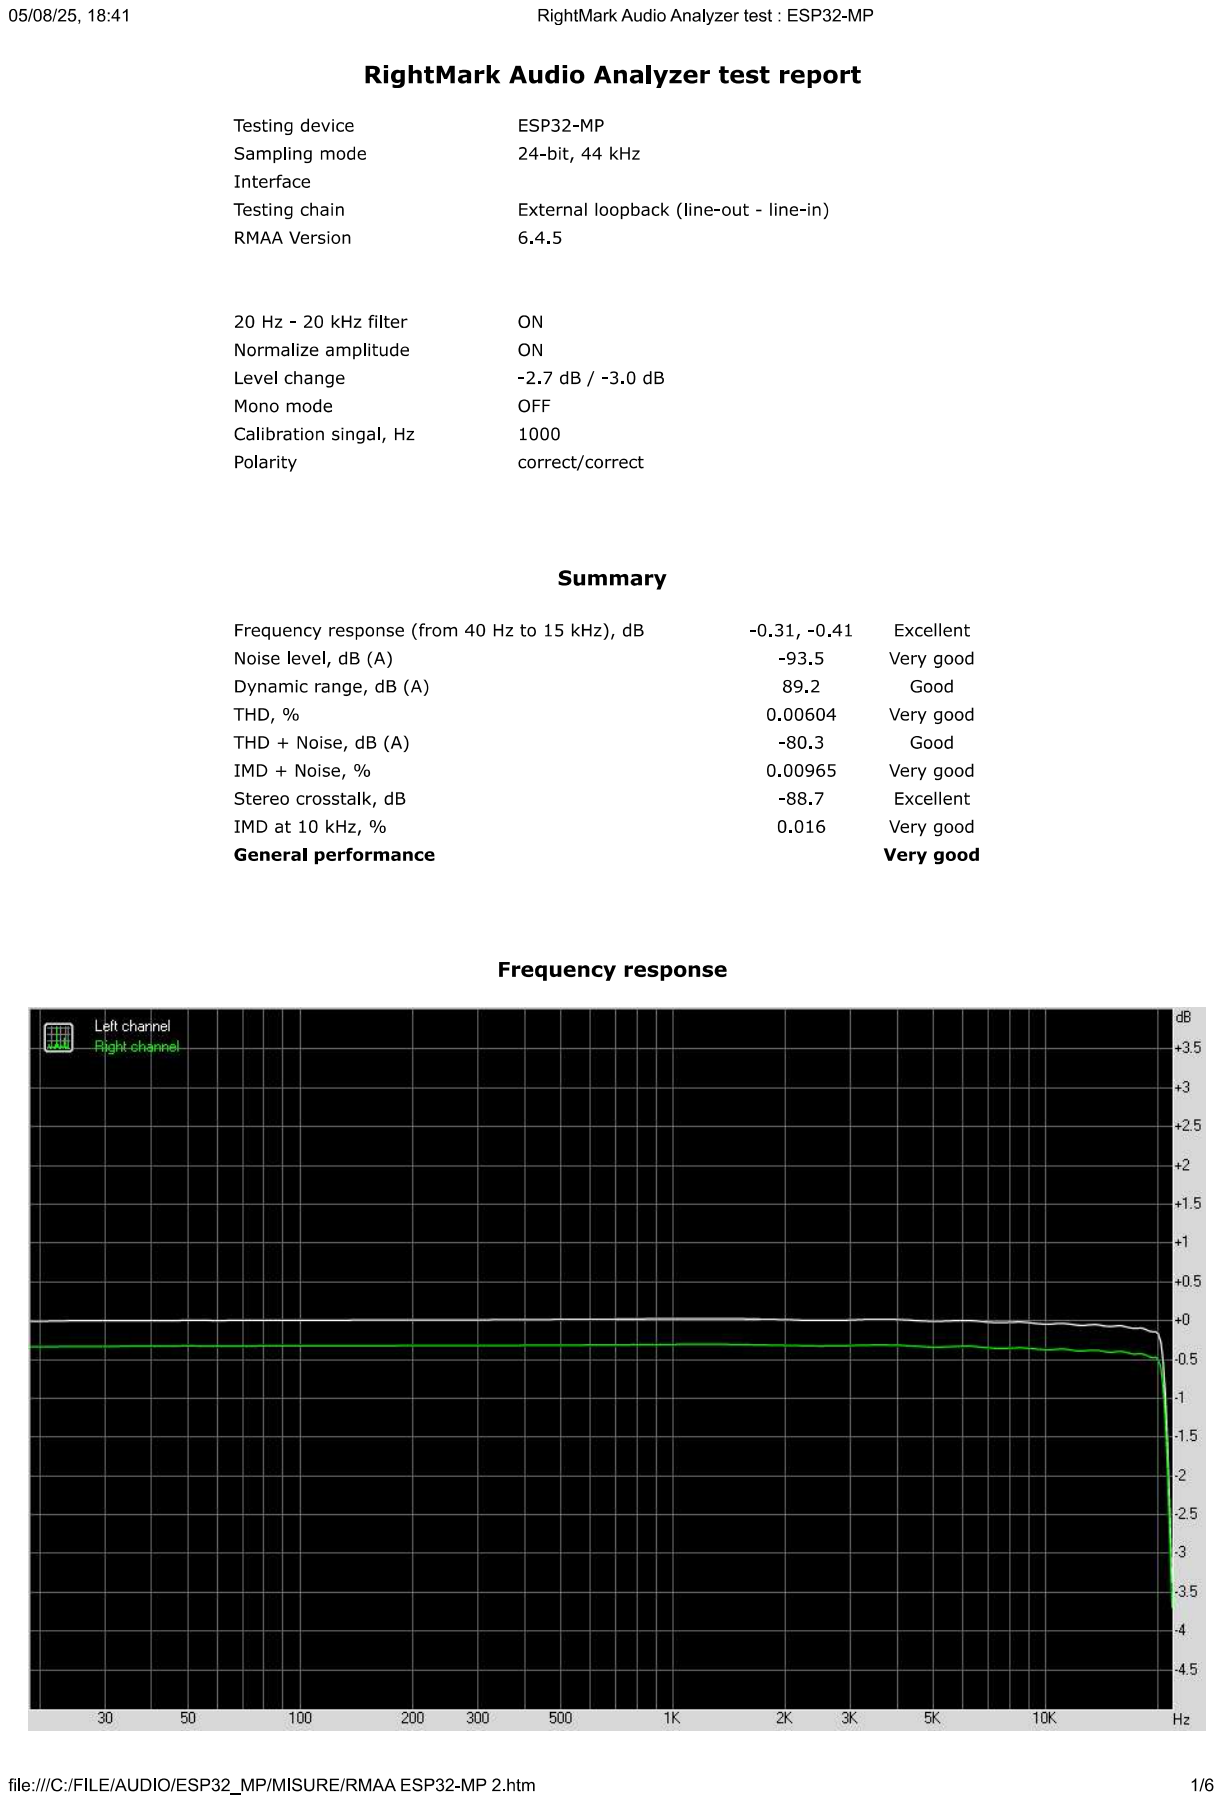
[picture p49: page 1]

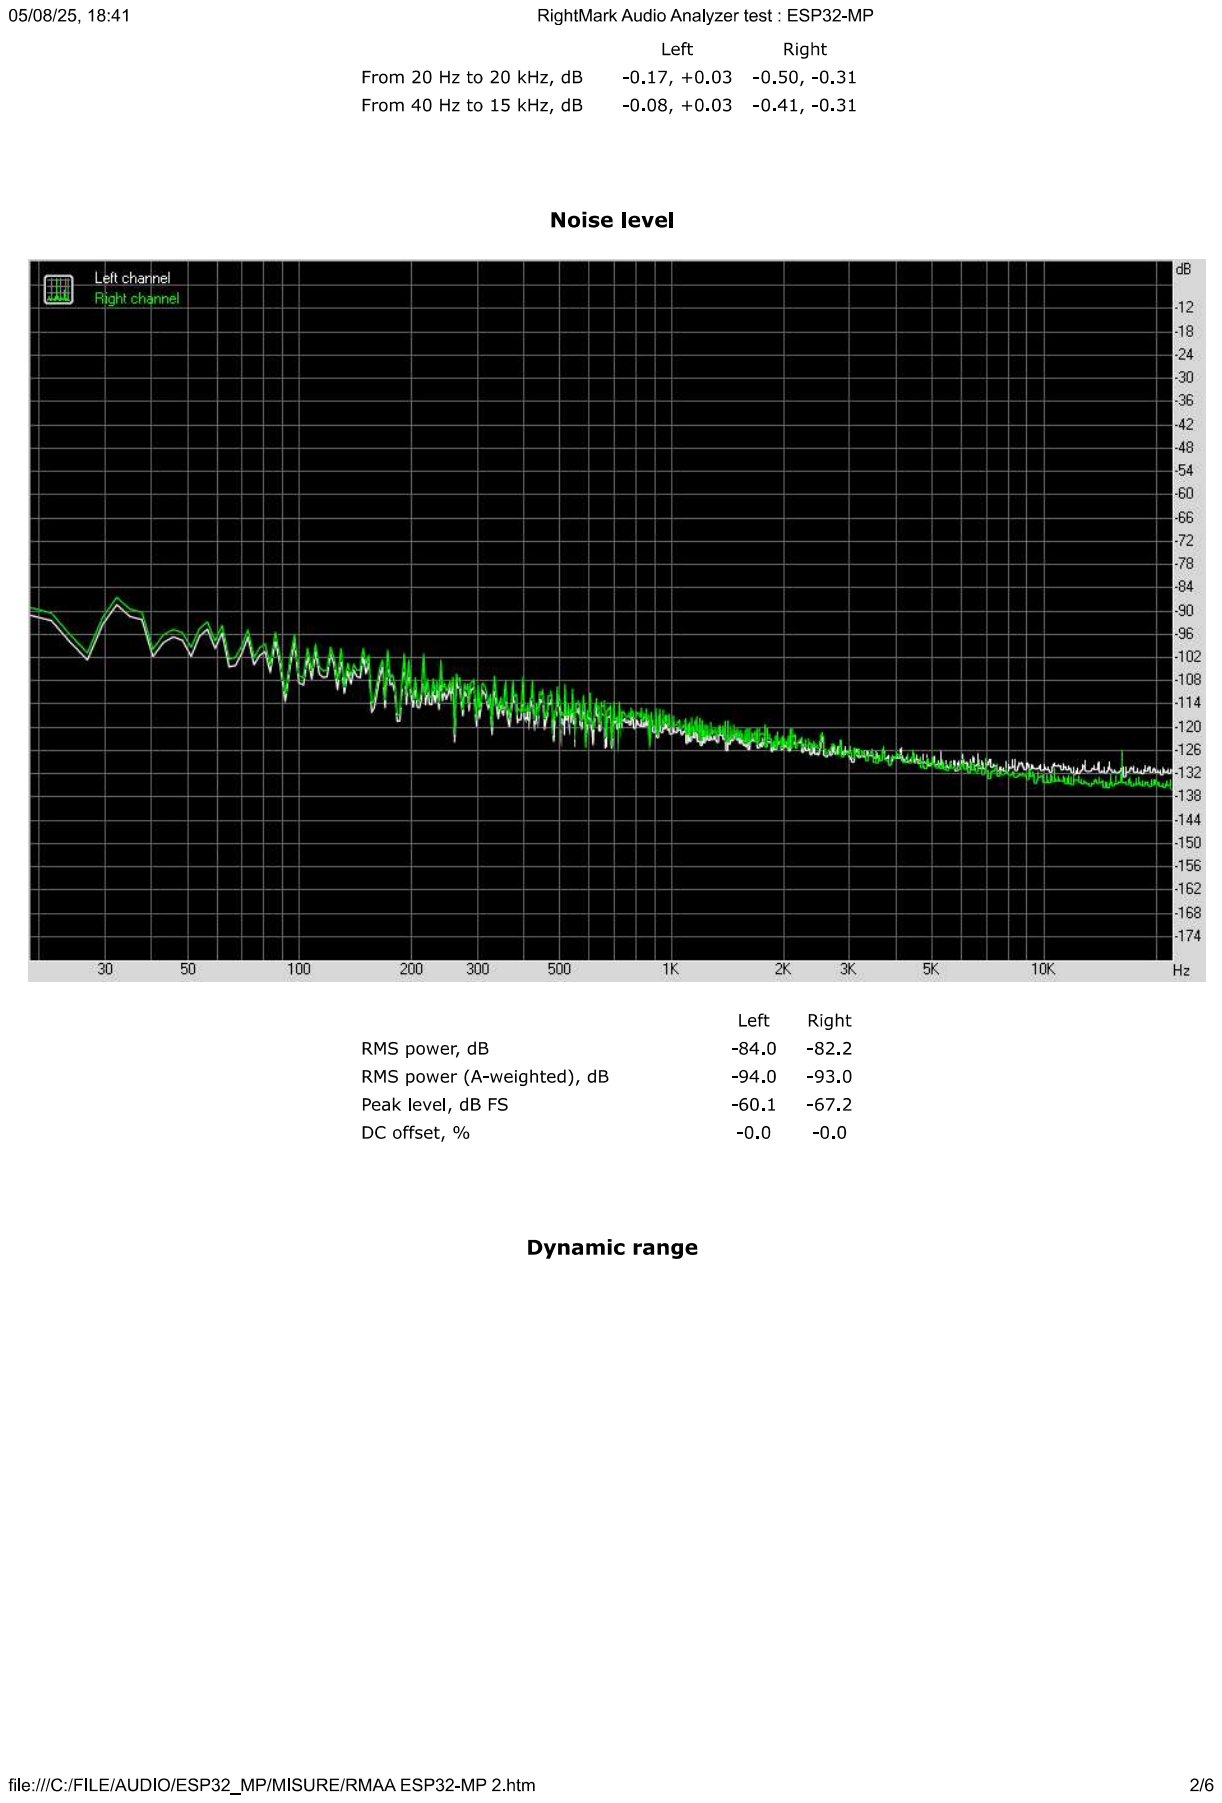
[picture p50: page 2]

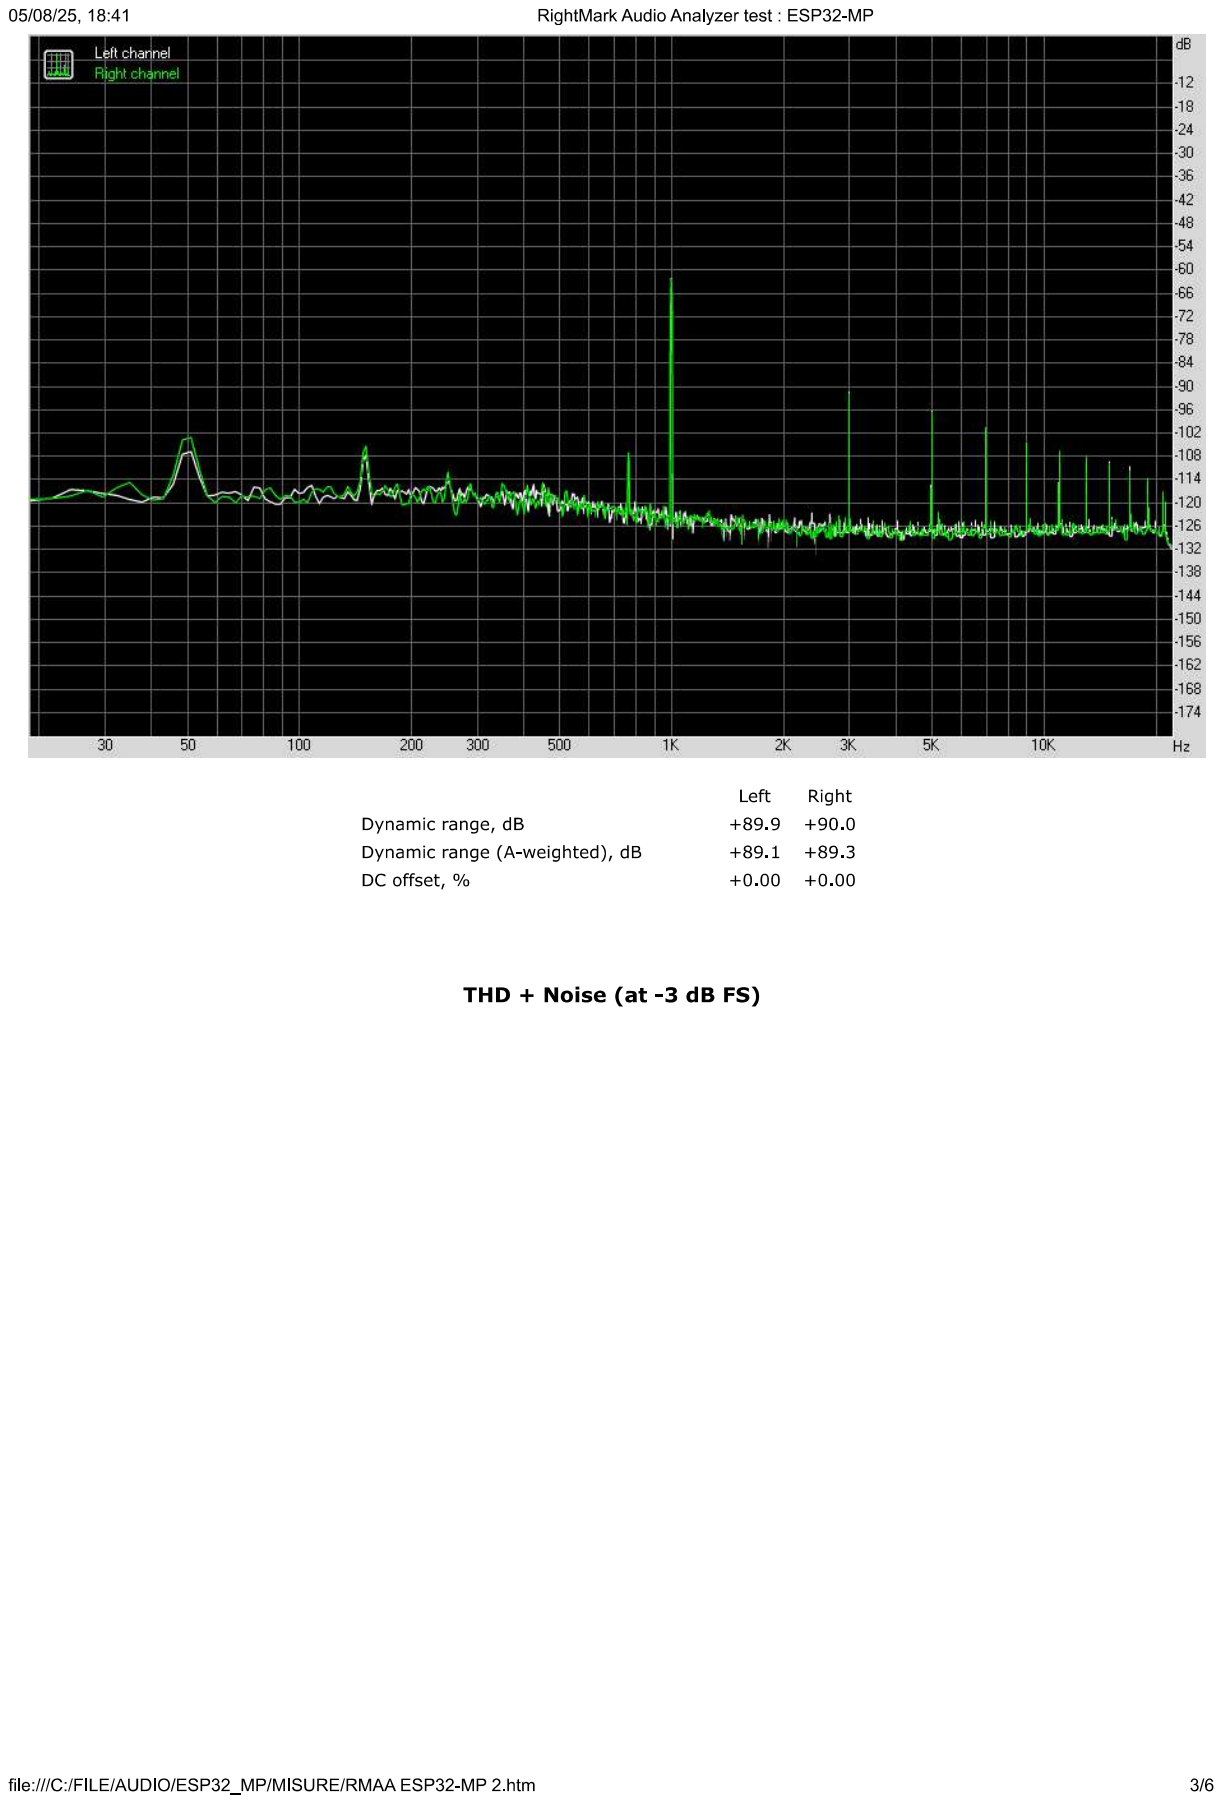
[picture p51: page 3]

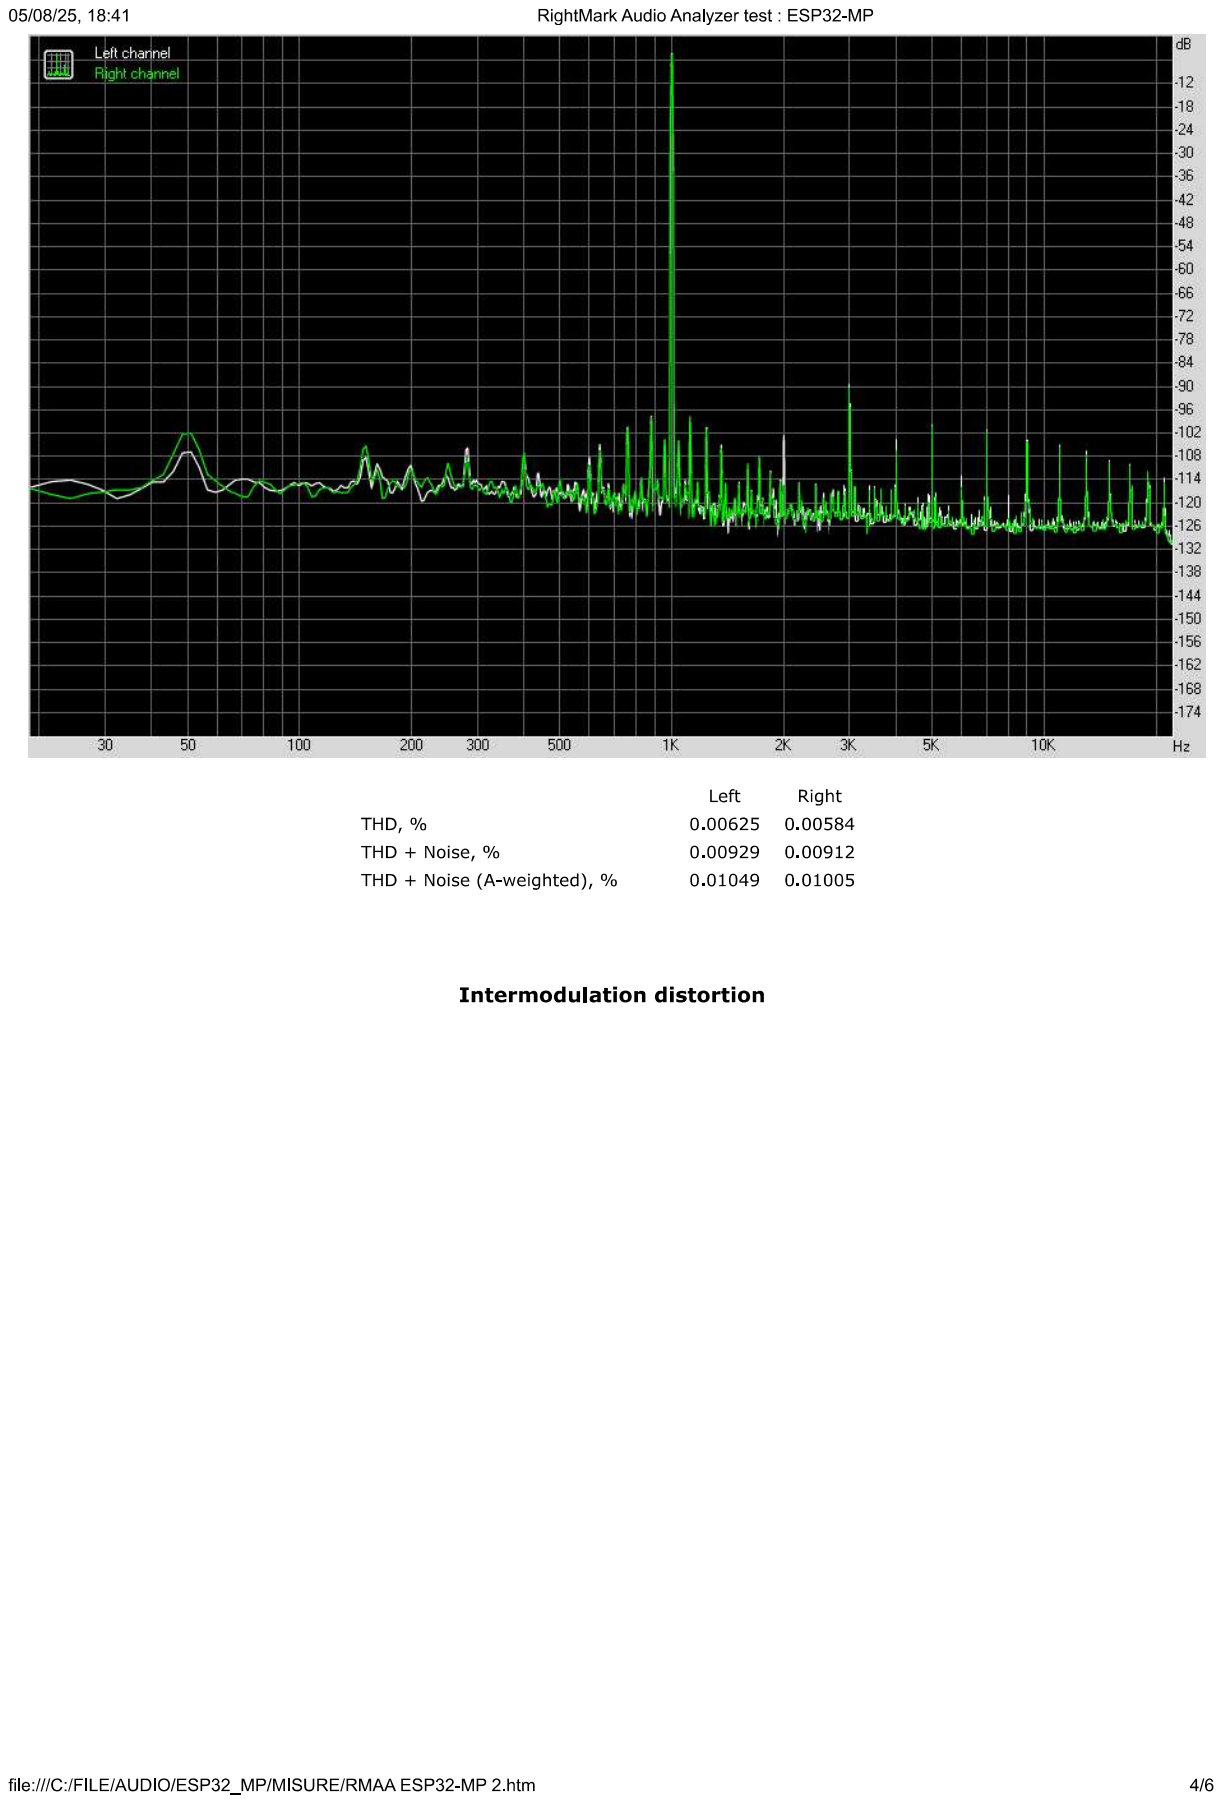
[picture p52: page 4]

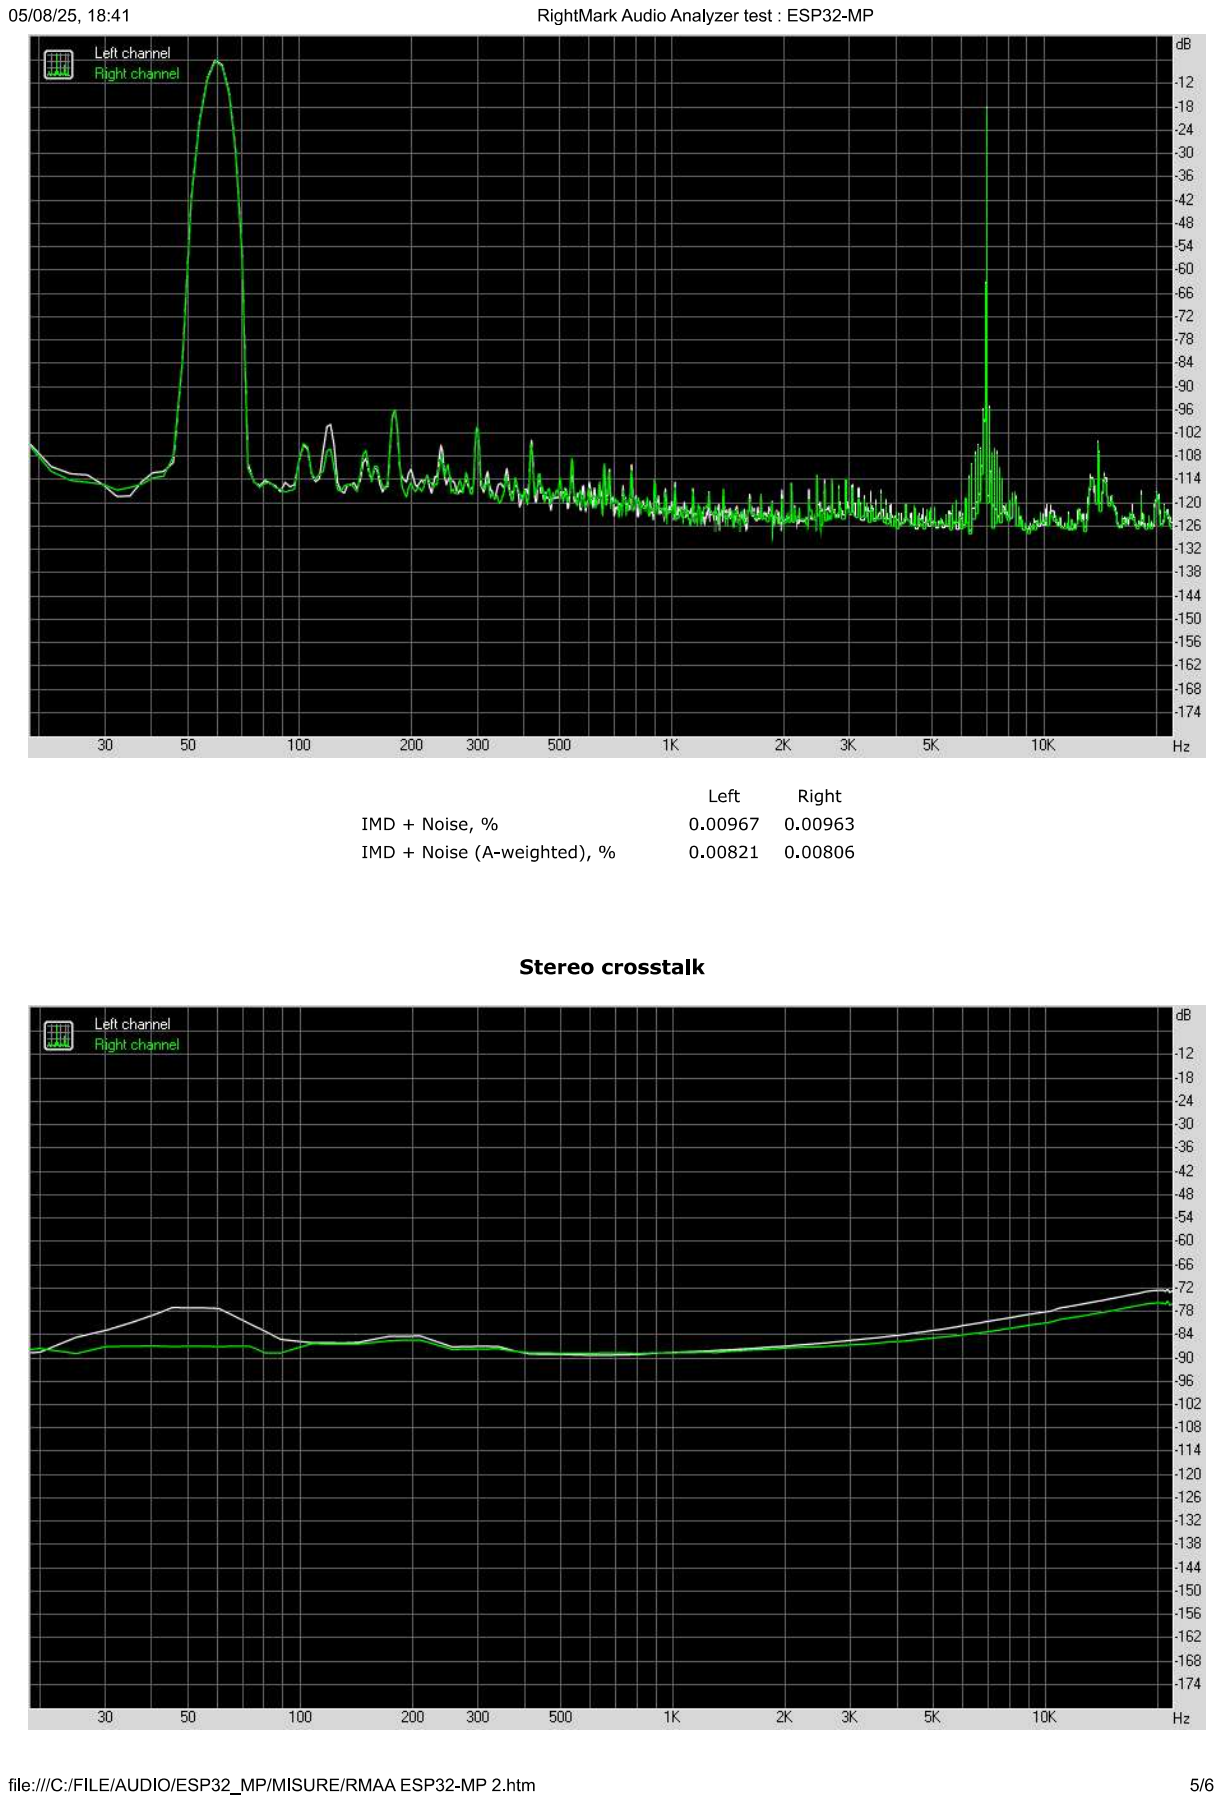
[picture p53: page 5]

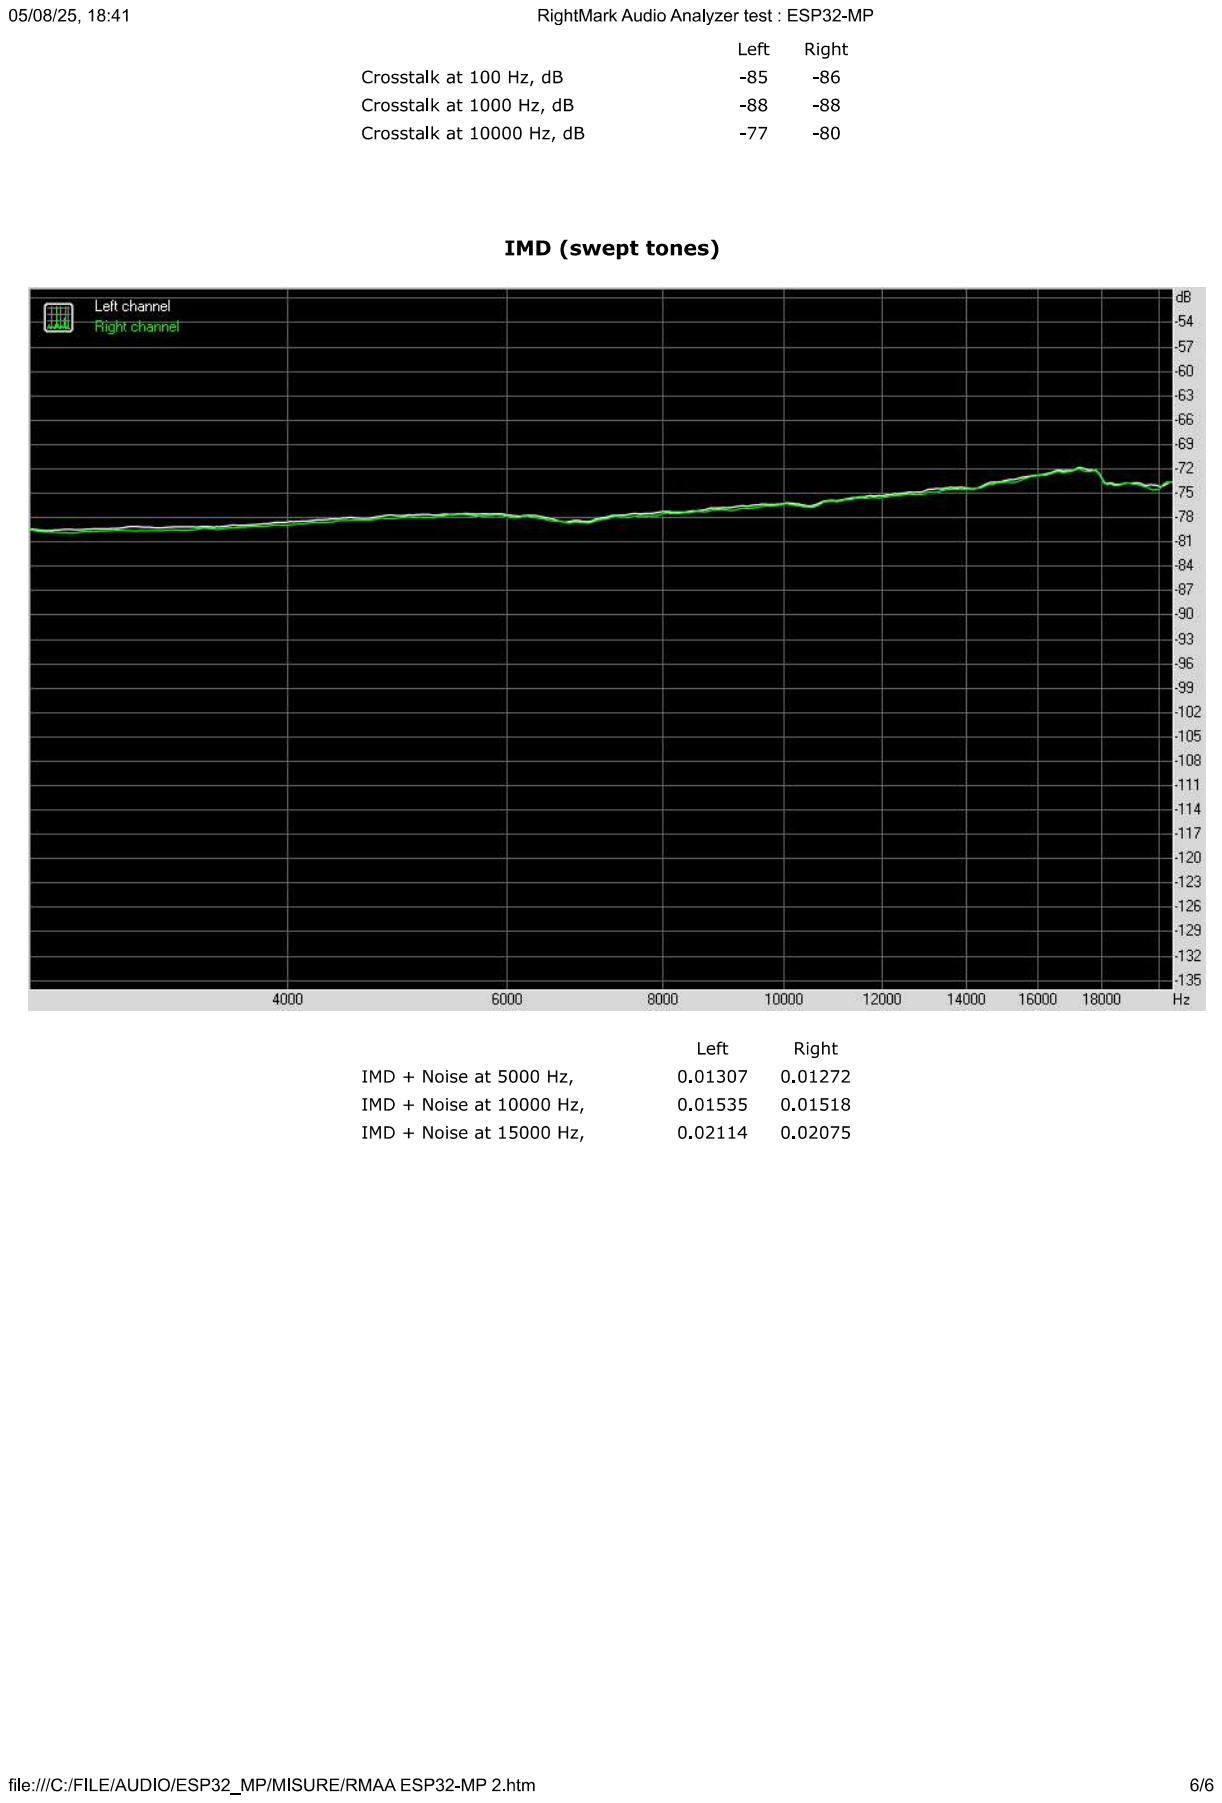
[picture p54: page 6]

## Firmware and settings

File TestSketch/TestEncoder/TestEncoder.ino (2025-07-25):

// TEST ENCODER
// ESP32_MP

#include "src/Button2/Button2.h"

/***** Encoder pins *****/
const byte pinEncA     = 36; //Data (Rpullup inclusa in encoder breakout)
const byte pinEncB     = 39; //CLK  (Rpullup inclusa in encoder breakout)
const byte pinEncPB    = 34; //PB   (Rpullup inclusa in encoder breakout)
volatile int encCount = 0;
volatile byte encState = 0;
//ESP32Encoder encoder;
Button2 EncPB;
bool disableEncPB=0;

void setup() 
{
   Serial.begin(115200);
   delay(100);
   Serial.println("Test Encoder");
   initEncoder();                  // Initialize encoder

}

void loop() 
{
    EncPB.loop();          // digital button service (Button2 lib)
    encService();

    /***** ENCODER SERVICE CW ROTATION *****/
    if (encCount > 0) //CW rotation INCREMENT
    {
       encCount = 0;
       Serial.println("+");
    }

    /***** ENCODER SERVICE CCW ROTATION *****/
    if (encCount < 0) //CCW rotation DECREMENT
    {
       encCount = 0;       
       Serial.println("-");   
    }
    
    delay(10);
}

// ENCODER BUTTON LONG PRESS EVENT 
void longClickDetected(Button2& btn) 
{
  Serial.println("Long click");        
}

// ENCODER BUTTON CLICK EVENT    
void released(Button2& btn) 
{
  Serial.println("Press Knob");
}

// Initialize Encoder Push Button 
void initEncoder()
{
    pinMode(pinEncA, INPUT);  // PULL UP già nella breakout board, add 100nF Capacitor
    pinMode(pinEncB, INPUT);    

    #define DEBOUNCE_MS 50
    #define LONGCLICK_MS 2000
    #define DOUBLECLICK_MS 3000
  
    EncPB.begin(pinEncPB);
    //EncPB.setPressedHandler(pressed);    
    EncPB.setReleasedHandler(released);  

    EncPB.setLongClickTime(LONGCLICK_MS);   
    EncPB.setLongClickDetectedHandler(longClickDetected); //quando è passato il tempo prastabilito mantenendo premuto il pulsante
    EncPB.setLongClickDetectedRetriggerable(false); //???    
}

// Run repeatedly Encoder Knob 
void encService()
{
  bool CHA = digitalRead(pinEncA);
  bool CHB = digitalRead(pinEncB);  
  switch (encState) {
    case 0:
      if (CHA==0 && CHB==1) encState=1;
      if (CHA==1 && CHB==0) encState=4;
      break;
    case 1:
      if (CHA==1 && CHB==1) encState=0;
      if (CHA==0 && CHB==0) encState=2;
      break;
    case 2:
      if (CHA==1 && CHB==0) encState=3;  
      if (CHA==0 && CHB==1) encState=1;    
      break;
    case 3:
      if (CHA==1 && CHB==1) { encState=0;  encCount++; }
      if (CHA==0 && CHB==0) encState=2;    
      break;      
    case 4:
      if (CHA==1 && CHB==1) encState=0;
      if (CHA==0 && CHB==0) encState=5;
      break;  
    case 5:
      if (CHA==0 && CHB==1) encState=6;
      if (CHA==1 && CHB==0) encState=4;
      break;   
    case 6:  
      if (CHA==1 && CHB==1) { encState=0;  encCount--; }
      if (CHA==0 && CHB==0) encState=5;    
      break;                
  }    
}

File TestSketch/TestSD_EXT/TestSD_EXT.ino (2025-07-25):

/*
  ESP32_MP TTGO T8 V1.8 TEST SD Card
  use EXTERNAL SD card reader HARDWARE SPI
*/

/***** SD Card Pins (SPI) *****/

#define SD_CS      4
#define SPI_MOSI  23
#define SPI_MISO  19
#define SPI_SCK   18



/* for use SD in BUS HSPI instead of VSPI
// configure this instance to use the 
// 2nd SPI bus called "HSPI" instead
// of the first, default bus "VSPI"
SPIClass sdSPI(HSPI);
// initialized the alternate SPI port and pin mappings
sdSPI.begin(SDM_CLK,SDM_MISO,SDM_MOSI,SDM_CS); //CLK,MISO,MOSI,CS

// initialize SD
if(!SD.begin(SDM_CS,sdSPI)){
    Serial.println(F("MicroSD Card Mount Failed"));
    return -1;
}
*/
 
 
#include <FS.h>
#include <SD.h>
#include <SPI.h>

void listDir(fs::FS &fs, const char * dirname, uint8_t levels){
    Serial.printf("Listing directory: %s\n", dirname);

    File root = fs.open(dirname);
    if(!root){
        Serial.println("Failed to open directory");
        return;
    }
    if(!root.isDirectory()){
        Serial.println("Not a directory");
        return;
    }

    File file = root.openNextFile();
    while(file){
        if(file.isDirectory()){
            Serial.print("  DIR : ");
            Serial.println(file.name());
            if(levels){
                listDir(fs, file.path(), levels -1);
            }
        } else {
            Serial.print("  FILE: ");
            Serial.print(file.name());
            Serial.print("  SIZE: ");
            Serial.println(file.size());
        }
        file = root.openNextFile();
    }
}


void setup(){
    Serial.begin(115200);
    delay(100);
    Serial.println("\n\nTEST EXTERNAL SD");

    const byte pinSDEnable   = 12;    
    pinMode(pinSDEnable, OUTPUT);
    digitalWrite(pinSDEnable, HIGH);      
    delay(1000);

    //use default SPI pins
    if(!SD.begin(SD_CS)){
        Serial.println("Card Mount Failed");
        return;
    }

    uint8_t cardType = SD.cardType();

    if(cardType == CARD_NONE){
        Serial.println("No SD card attached");
        return;
    }

    Serial.print("SD Card Type: ");
    if(cardType == CARD_MMC){
        Serial.println("MMC");
    } else if(cardType == CARD_SD){
        Serial.println("SDSC");
    } else if(cardType == CARD_SDHC){
        Serial.println("SDHC");
    } else {
        Serial.println("UNKNOWN");
    }

    uint64_t cardSize = SD.cardSize() / (1024 * 1024);
    Serial.printf("SD Card Size: %lluMB\n", cardSize);
    Serial.printf("Total space: %lluMB\n", SD.totalBytes() / (1024 * 1024));
    Serial.printf("Used space: %lluMB\n", SD.usedBytes() / (1024 * 1024));
    delay(1000);
    listDir(SD, "/", 0);
}

void loop(){
  delay(100);
}
